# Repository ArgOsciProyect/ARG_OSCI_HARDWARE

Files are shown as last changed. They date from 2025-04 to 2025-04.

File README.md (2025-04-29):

# ARG_OSCI Hardware Implementation Guide



**ARG_OSCI** is an open-source portable oscilloscope platform. This document details the technical implementation of the hardware, focusing on design decisions, construction, and improvement opportunities. It is intended for engineers and advanced users interested in building or modifying the device.

---

## Table of Contents
- [Introduction](#introduction)
- [Design Overview](#design-overview)
- [Implementation Details](#implementation-details)
  - [1. Input Network](#1-input-network)
  - [2. Attenuation Networks](#2-attenuation-networks)
    - [2.1 A/B Attenuation Network](#ab-attenuation-network)
    - [2.2 1/2/3/4 Attenuation Network](#1234-attenuation-network)
    - [2.3 Attenuation Stage Details](#attenuation-stage-details)
  - [3. Amplification Stage](#3-amplification-stage)
  - [4. Signal Filtering](#4-signal-filtering)
  - [5. External ADC Circuit](#5-external-adc-circuit)
  - [6. Transient Comparator Circuit](#6-transient-comparator-circuit)
  - [7. Calibration Square Wave Generator](#7-calibration-square-wave-generator)
  - [8. Connection Status LED Circuit](#8-connection-status-led-circuit)
  - [9. Power Supply](#9-power-supply)
  - [10. ESP32 Connectivity and Decoupling](#10-esp32-connectivity-and-decoupling)
- [Design Files and Resources](#design-files-and-resources)
- [Construction and Improvement Notes](#construction-and-improvement-notes)
  - [1. Assembly and Component Selection](#assembly-and-component-selection)
  - [2. Protection and Safety](#protection-and-safety)
  - [3. Optional Simplifications](#optional-simplifications)
  - [4. Design and Layout](#design-and-layout)
  - [5. PCB Design](#pcb-design)
  - [6. 3D Case Design](#3d-case-design)
- [Pending Tasks and Recommendations](#pending-tasks-and-recommendations)
  - [1. Technical Improvements](#technical-improvements)
  - [2. Documentation and Usability](#documentation-and-usability)
  - [3. Future Development](#future-development)
- [License](#license)
- [Acknowledgements](#acknowledgements)

---

## Introduction

This document describes how to implement the ARG_OSCI hardware, including the rationale behind each design block, construction notes, and suggestions for further development. For usage instructions, refer to the user manual.

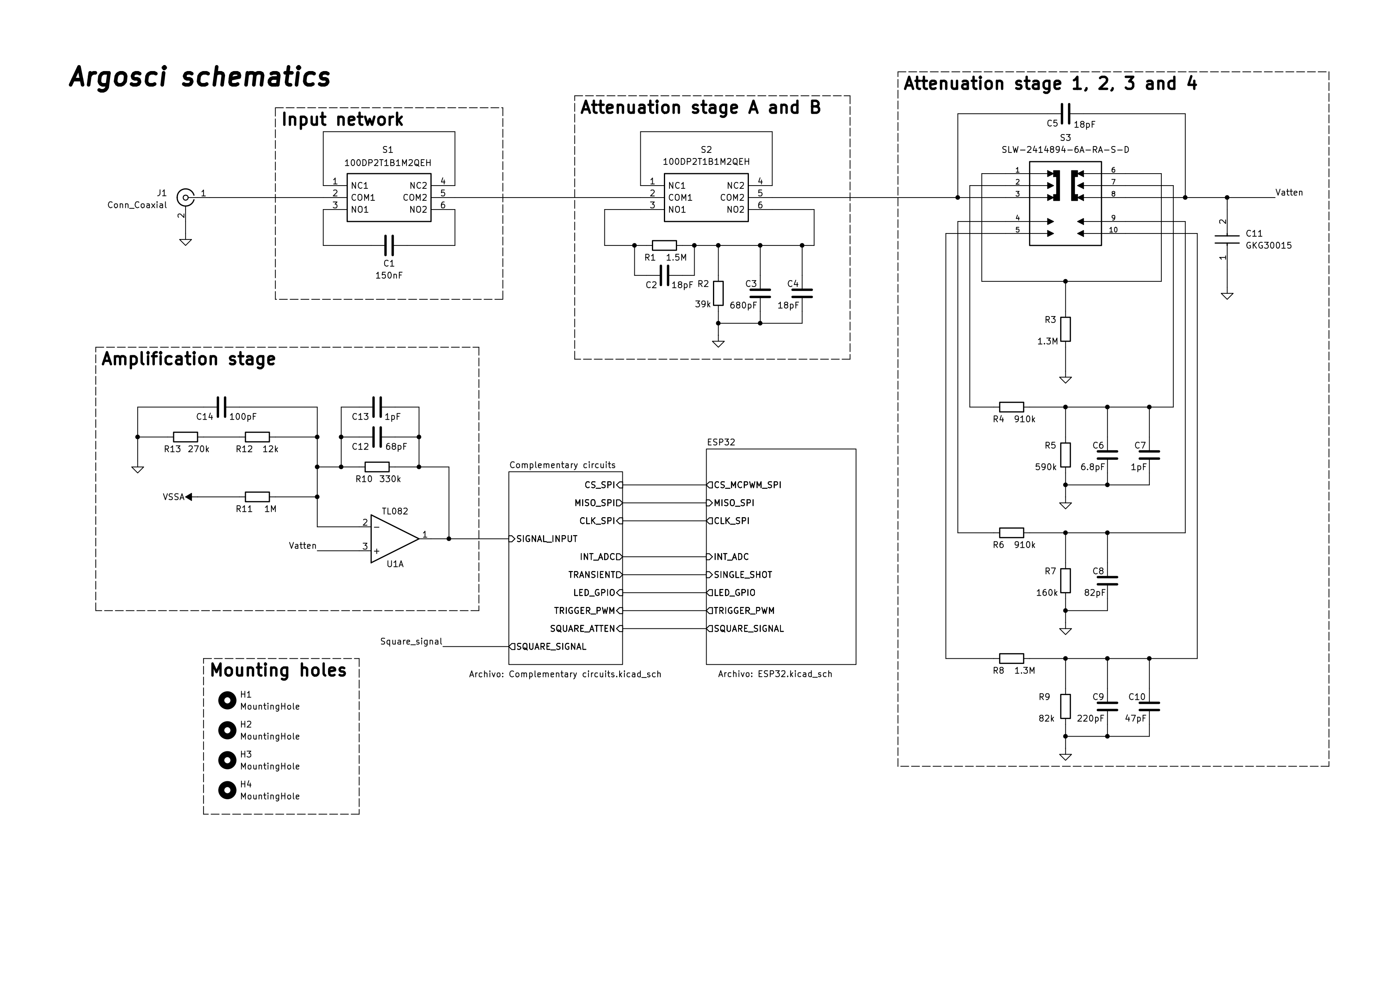
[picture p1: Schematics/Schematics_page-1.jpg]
Argosci Schematics

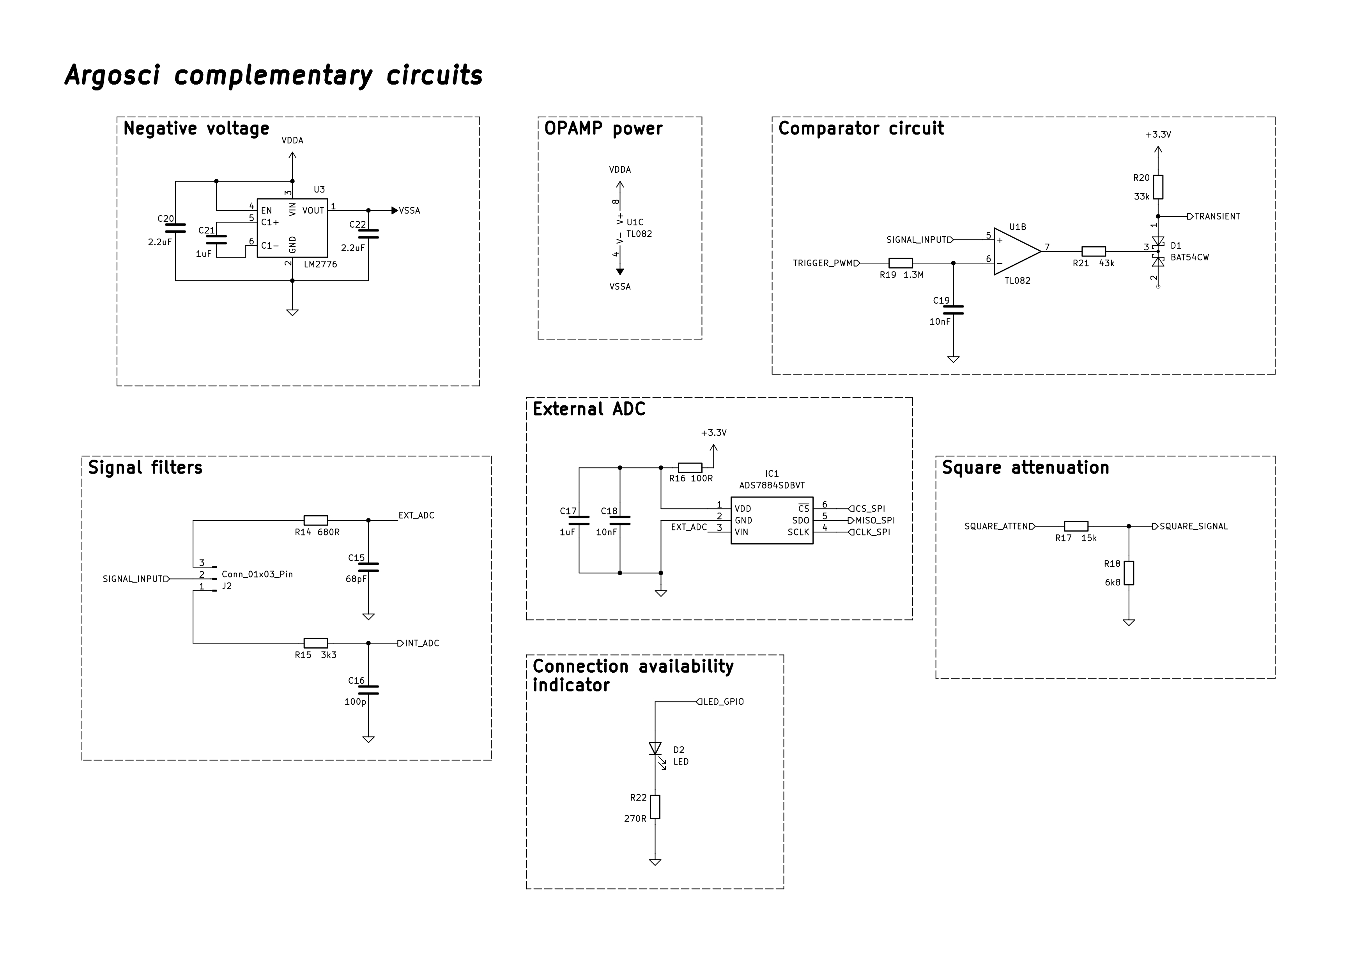
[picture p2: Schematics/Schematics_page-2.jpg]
Argosci complementary circuits

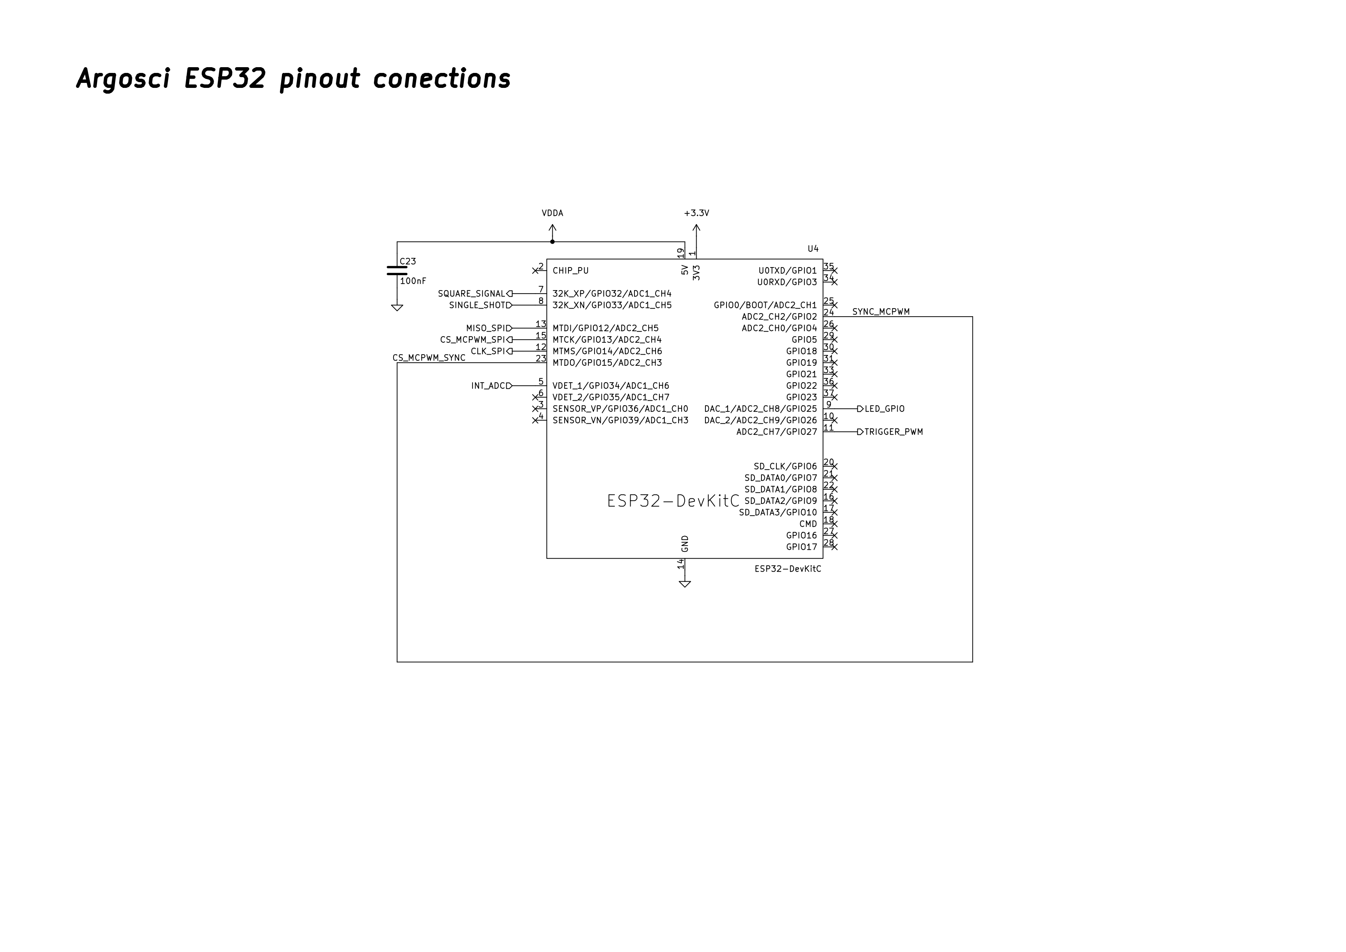
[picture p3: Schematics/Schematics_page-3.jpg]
Argosci ESP32 pinout conections


## Design Overview

The hardware is divided into several functional blocks:

- Input Network
- Attenuation Networks
- Attenuation Stage Details
- Amplification Stage
- Signal Filtering
- External ADC Circuit
- Transient Comparator Circuit
- Calibration Square Wave Generator
- Connection Status LED Circuit
- Power Supply
- ESP32 Connectivity and Decoupling

---

## Implementation Details

### 1. Input Network

The input network provides both AC and DC coupling paths. The AC coupling path includes a series capacitor (150 nF), while the DC path is direct. The 150 nF capacitor must be rated for at least 500V to safely block DC voltages up to the device's maximum scale (±400V). The capacitor value was selected to achieve a cutoff frequency below 1 Hz, considering that the input impedance is always greater than 1MΩ (typically 1070 MΩ to 1500 MΩ, depending on the attenuation setting). This configuration forms a high-pass filter and ensures accurate measurement of AC signals above 1Hz, with a settling time of approximately 1 second after switching to AC coupling.

<!--**Expansion note:** You may add a graph of the high-pass filter response.-->

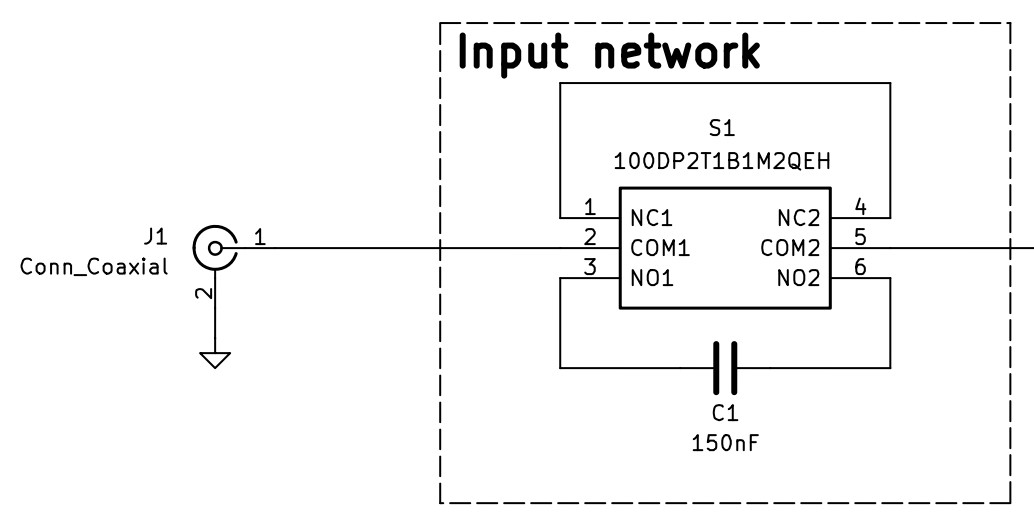
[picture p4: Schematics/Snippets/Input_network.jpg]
Input network


### 2. Attenuation Networks
#### 2.1. A/B Attenuation Network
Provides coarse attenuation (e.g., ×40) using resistor dividers and mechanical switches (2P2T selector switch).

#### 2.2. 1/2/3/4 Attenuation Network
Provides fine attenuation (e.g., ×2.4), yielding eight selectable voltage ranges in combination with the A/B network. This stage also uses mechanical switches (2P4T selector switch) and resistor divider networks for attenuation.

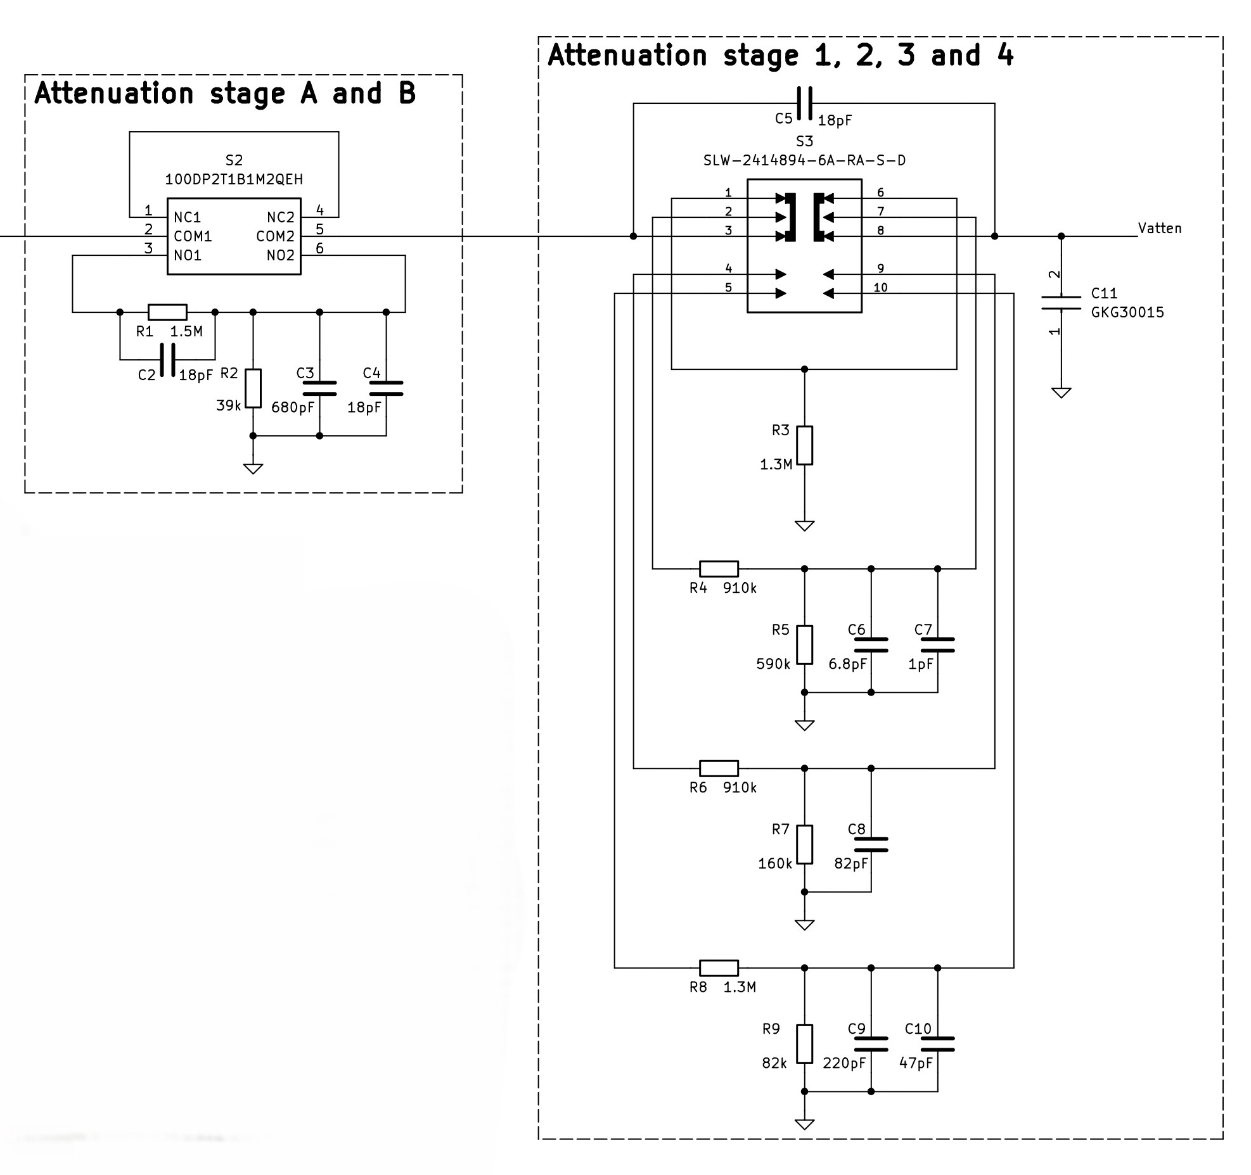
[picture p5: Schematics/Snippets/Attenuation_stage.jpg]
Attenuation stage


#### 2.3. Attenuation Stage Details

The decision to use resistive divider networks in the attenuation stage was made after a thorough analysis of various possible configurations. Different approaches were evaluated based on criteria such as ease of compensation, the number of switches required for implementation, the impedance presented to the amplifier, and other relevant aspects. The chosen solution represents a balance between precision, simplicity, and robustness for the application.

The attenuation stage is designed to maintain an input impedance greater than 1 MΩ. To compensate for the effects of parasitic capacitances —particularly those introduced by the amplifier— capacitors are included in the attenuation network. The total input capacitance of the device is kept below 20pF. Components are selected with 5% tolerance (1% for higher precision if desired), resistors are rated at 1/4 W, and capacitors are rated for at least 25 V, except for the series capacitor in stage B, which must withstand up to 500 V to safely attenuate signals up to 400V when required.

A trimmer capacitor is placed at the amplifier input to allow fine adjustment and compensate for variations in the amplifier’s input capacitance and other component tolerances. The trimmer is adjustable up to 20pF, with a minimum value of approximately 4.2pF, ensuring a flat frequency response across the device’s bandwidth. The most sensitive stage to these variations is A2, as it has the smallest capacitance in parallel with the amplifier, making it more susceptible to frequency response deviations.

### 3. Amplification Stage

The amplification stage uses the TL082 operational amplifier, chosen for its suitable bandwidth, slew rate, operating ranges, low associated errors, low cost, and ease of sourcing. Two feedback configurations are implemented: the inverting configuration is used to set the signal offset (centering it within the ADC input range using the –5V rail), while the non-inverting configuration amplifies the measured signal to maximize the ADCs' dynamic range.

To minimize errors due to input bias currents, high-value resistors are used in the feedback network. This necessitated the inclusion of a capacitive compensation network (without the need for a trimmer in this case).

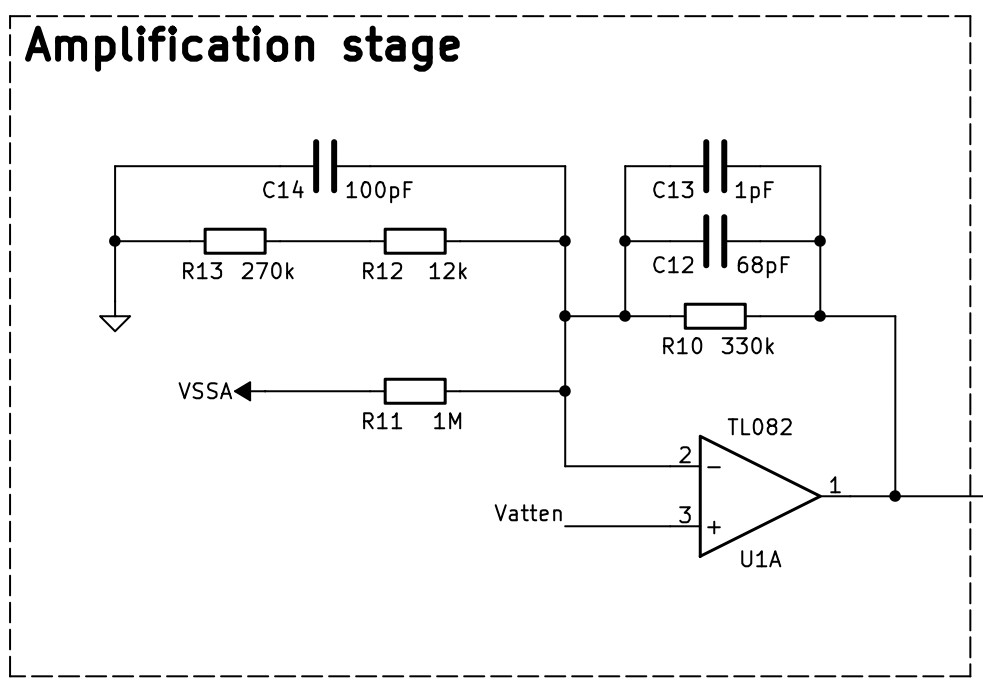
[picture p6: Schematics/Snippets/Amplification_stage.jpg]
Amplification stage

<!--**Expansion note:** Discuss op-amp selection criteria, possible improvements, and test results.-->

#### Design Considerations and Potential Improvements
- **Resistor Value Optimization:** It is being considered to reduce the values of the feedback resistors, as the error from bias currents is relatively low. Lowering these values could allow the removal of the compensation network, though a capacitor should still be retained to filter noise from the –5V supply. This change would increase the device's power consumption and should be evaluated accordingly.
- **Negative Voltage Limiter:** It is recommended to add a negative voltage limiter at the amplifier output. While the amplifier typically saturates at positive voltages (not damaging the ADCs), under certain conditions it may output voltages below 0V, which could potentially harm the ADCs.

### 4. Signal Filtering

A conventional first-order RC low-pass filter is used for signal filtering. The filters are designed based on the input capacitance of the ADCs used in each case. Two separate filter networks are implemented, allowing the user to select which ADC to use. For each network, the cutoff frequency is set to the maximum frequency that the device can accurately measure with the selected ADC.

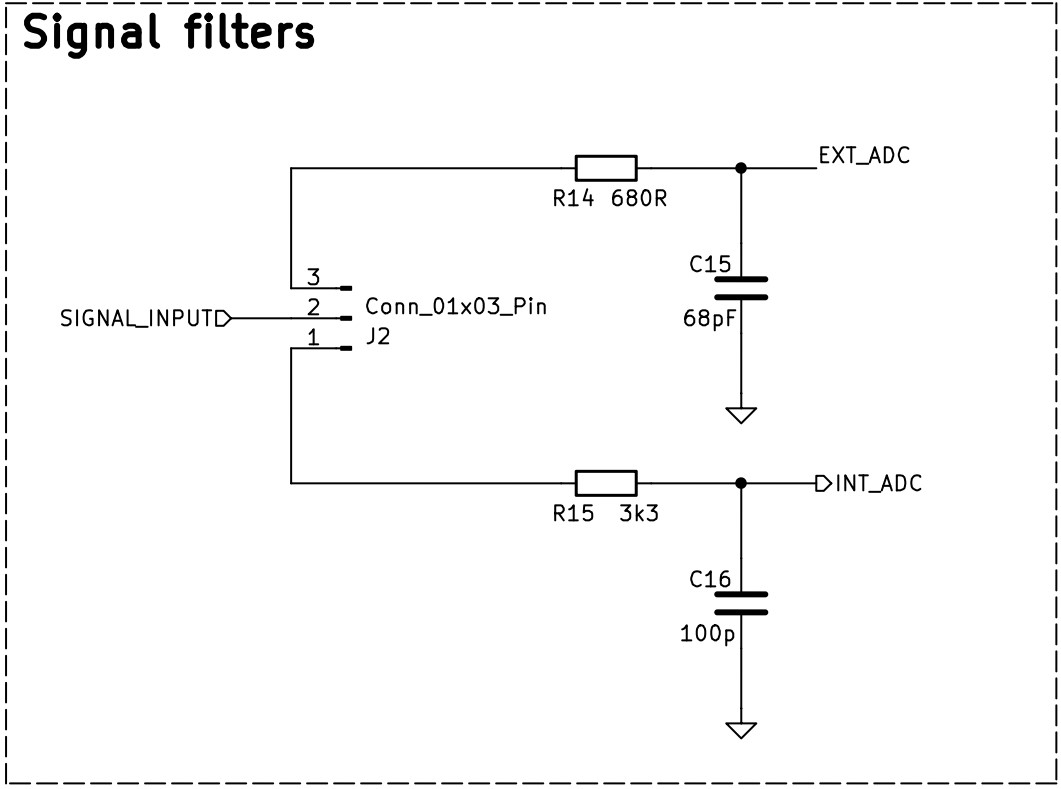
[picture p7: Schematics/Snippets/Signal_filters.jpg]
Signal filters


#### Design Considerations and Potential Improvements
- **Filter Effectiveness Review:** It has been observed that at higher frequencies, aliasing phenomena may occur, distorting the measured signal and its frequency spectrum. A review of the filter effectiveness is recommended, and higher-order filters may be considered to improve performance and reduce aliasing effects.

### 5. External ADC Circuit

The external ADC (ADS7884) circuit is designed following the manufacturer's recommendations. For SPI communication with the ESP32, the layout ensures physical proximity between the ADS7884 and the relevant ESP32 pins, with all SPI traces kept as short and equal in length as possible. These measures are critical to maintain signal integrity at the 40 MHz communication frequency.

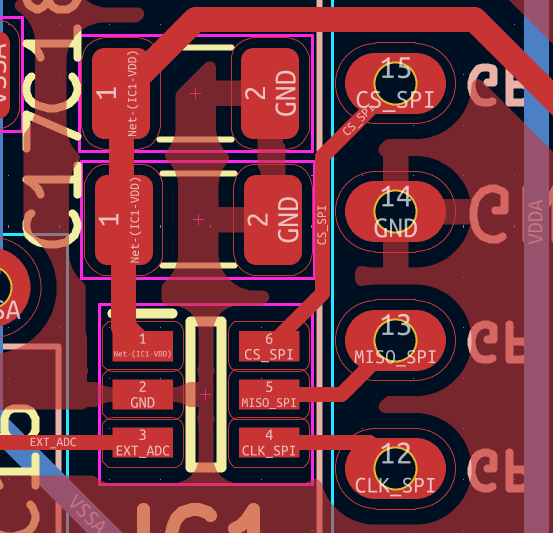
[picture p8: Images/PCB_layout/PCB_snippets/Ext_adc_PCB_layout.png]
External ADC - PCB layout


The ADS7884 is powered by the 3.3 V supply provided by the ESP32's onboard regulator, which also serves as the ADC's voltage reference. The stability of this voltage is crucial for measurement accuracy. To stabilize the supply, an RC network is implemented, consisting of the manufacturer-recommended capacitors and a 100 Ω resistor (subject to further review), in line with the recommended power supply impedance.

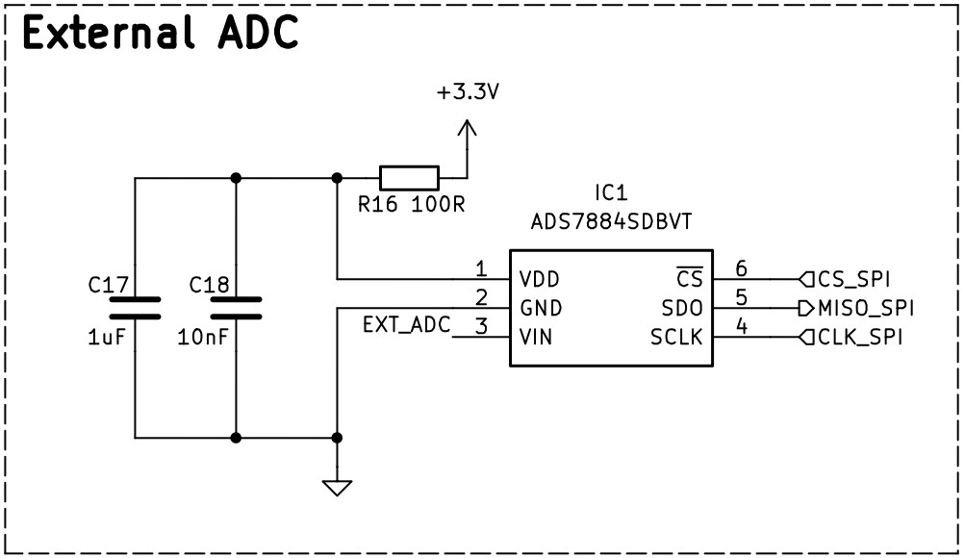
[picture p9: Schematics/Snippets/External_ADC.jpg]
External ADC


#### Design Considerations and Potential Improvements
- **Dedicated Voltage Regulator:** It is recommended to consider adding a dedicated voltage regulator for the ADC to ensure a stable reference voltage, independent of noise from the ESP32 supply.
- **Power Supply Filtering Review:** The value of the series resistor and the overall RC network should be reviewed and optimized to further improve voltage stability and measurement quality.
- **EMI/Environmental Noise Shielding:** The ADC has shown sensitivity to environmental interference and noise. It is recommended to implement shielding methods on the PCB or enclosure to reduce these effects and improve measurement reliability.

### 6. Transient Comparator Circuit

The transient comparator circuit enables the detection and reading of aperiodic (transient) signals. It consists of three main parts, each with a specific function:

#### RC Filter
The RC filter stabilizes a PWM signal generated by the ESP32. This PWM signal is set to have an average voltage equal to the trigger level selected in the application for signal visualization. The resulting DC voltage serves as the reference level for the comparator.

#### Comparator (TL082)
The remaining amplifier in the TL082 IC is configured as a comparator. It compares the measured signal to the reference voltage from the RC filter. When the input signal exceeds the trigger threshold, the comparator switches its output state. This transition is recognized as a transient event, which is then communicated to the application for display.

#### Digital Signal Adapter
The digital adapter converts the output of the comparator to voltage levels that are safe and readable by the ESP32: 3.3 V (minimum 2.475 V) for logic high and 0 V (maximum 0.825 V) for logic low. This is achieved using a BAT54 (or BAT85) diode in combination with a resistive divider, which limits current and ensures the output is pulled close to 0 V when the comparator switches to its negative output.

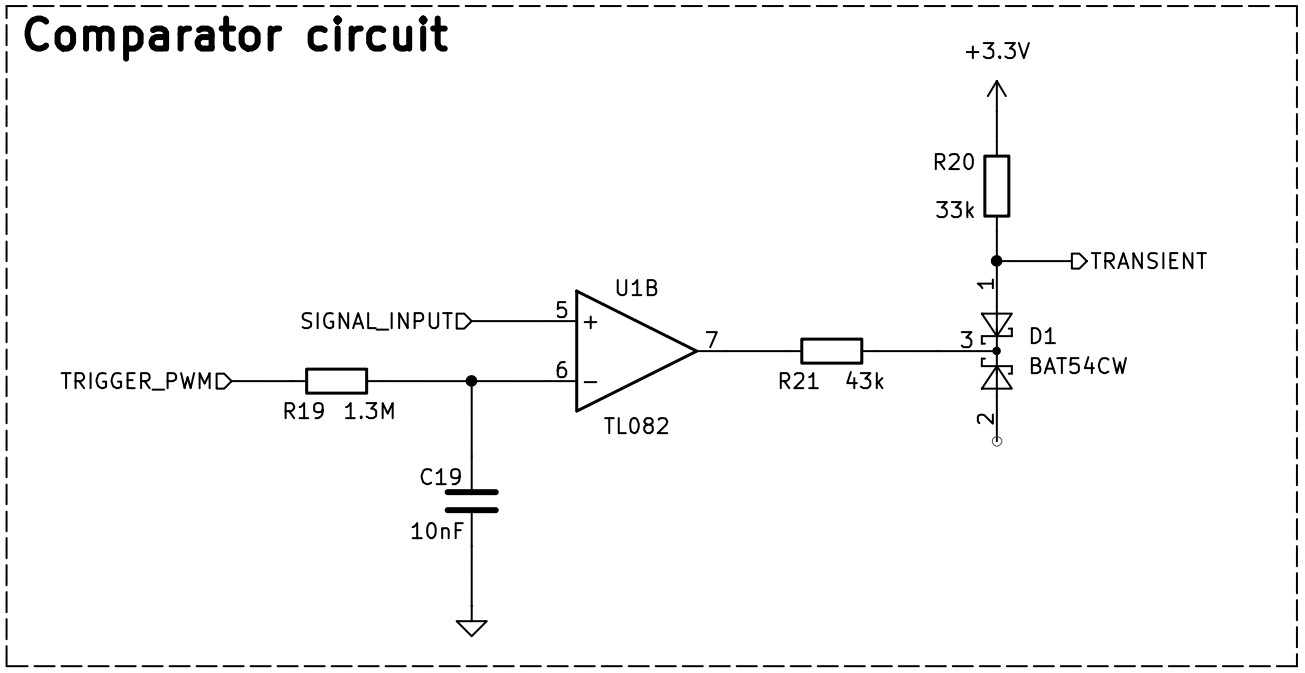
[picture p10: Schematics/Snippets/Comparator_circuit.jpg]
Comparator circuit


<!--**Expansion note:** Add timing diagrams or oscilloscope captures of transient detection events.-->

### 7. Calibration Square Wave Generator

The calibration circuit operates using a 1 kHz square wave signal provided by the ESP32, with levels ranging from 0 V to 3.3 V. This signal is attenuated to approximately 30% of its original amplitude using a resistive divider (15 kΩ and 6.8 kΩ), resulting in a safe level for the A2 stage, which is particularly sensitive to parasitic capacitance. The attenuated signal is used specifically to fine-tune the trimmer capacitor in the A2 stage. The resistor values are selected to minimize current draw and reduce loading on the ESP32 output.

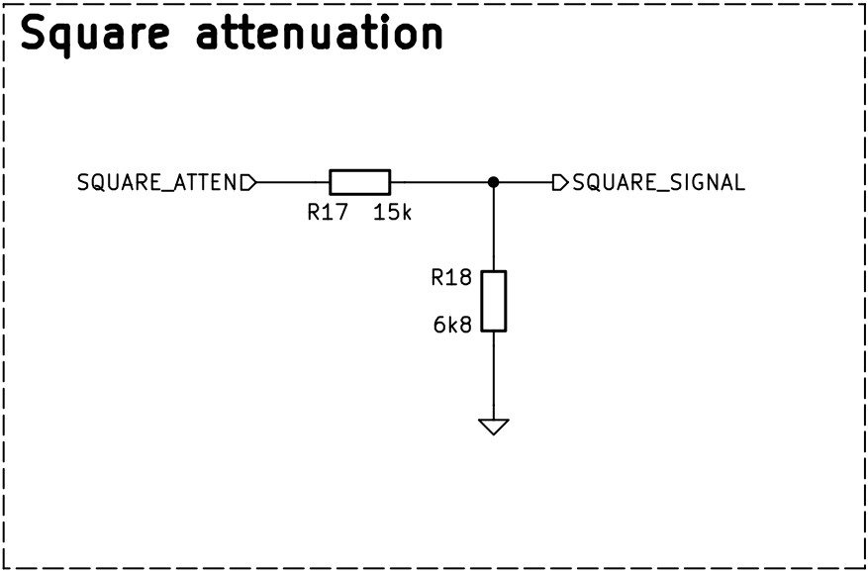
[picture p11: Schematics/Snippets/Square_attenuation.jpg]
Square attenuation


### 8. Connection Status LED Circuit

The purpose of this LED is to indicate when the ESP32 board is ready to accept WiFi connections and begin operation. While the LED is off, the device is generating the access point. When the LED turns on, it signals that the user can connect to the device.

A 5 mm LED is used to increase visibility. A 270 Ω resistor is placed in series, but this value can be adjusted if needed—for example, using a lower resistance to increase brightness. The LED size and resistor value can be modified according to specific design preferences.

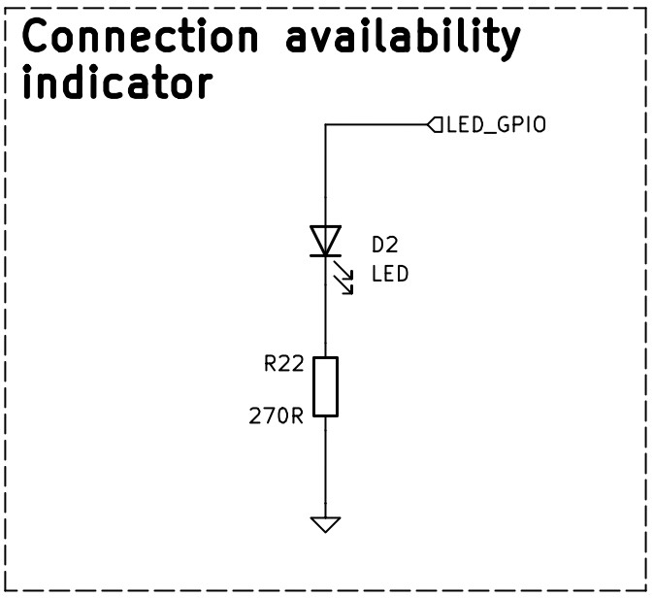
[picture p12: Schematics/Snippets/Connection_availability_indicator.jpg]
Connection availability indicator


### 9. Power Supply
#### 9.1. +5V Supply
- The +5V supply is sourced from the ESP32's 5V pin, which itself is powered via the USB port.
- A diode-capacitor circuit is used between the USB input and the 5V rail. The presence of the diode causes a slight voltage drop below 5V. While this does not affect the operation of the operational amplifiers, it does slightly shift the voltage levels in the comparator circuit and significantly impacts the generation of the –5V rail via the LM2776.

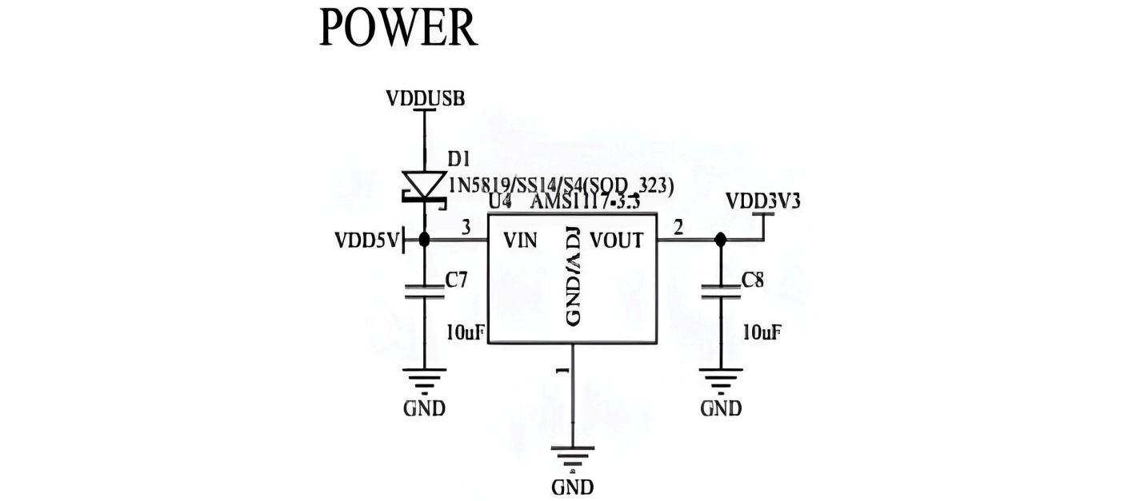
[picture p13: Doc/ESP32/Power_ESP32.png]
Power ESP32

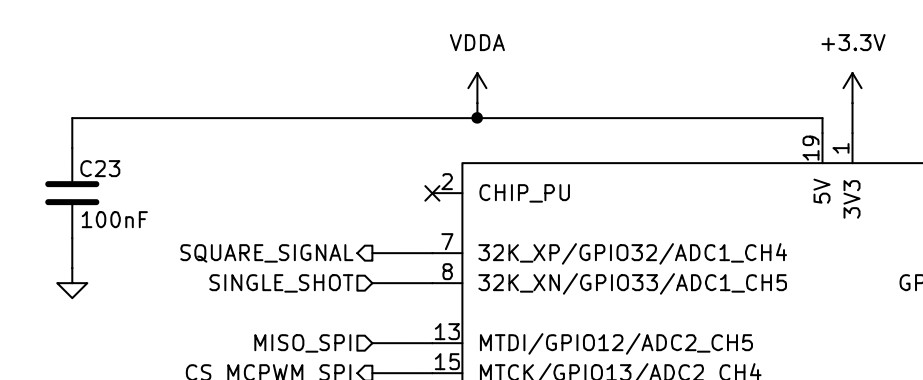
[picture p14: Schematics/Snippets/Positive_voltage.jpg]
Positive voltage


#### 9.2. –5V Supply
- The –5V rail is generated using the LM2776 charge pump IC, implemented according to the manufacturer's recommendations.
- Stabilization and voltage generation capacitors are placed as close as possible to the LM2776 to ensure proper operation and minimize noise.
- Since the LM2776 inverts and slightly alters the positive supply voltage, software and firmware corrections are applied to compensate for any offset shifts that could affect ADC readings.
- There is a known issue with the LM2776 operation that requires further review to ensure reliable negative voltage generation.

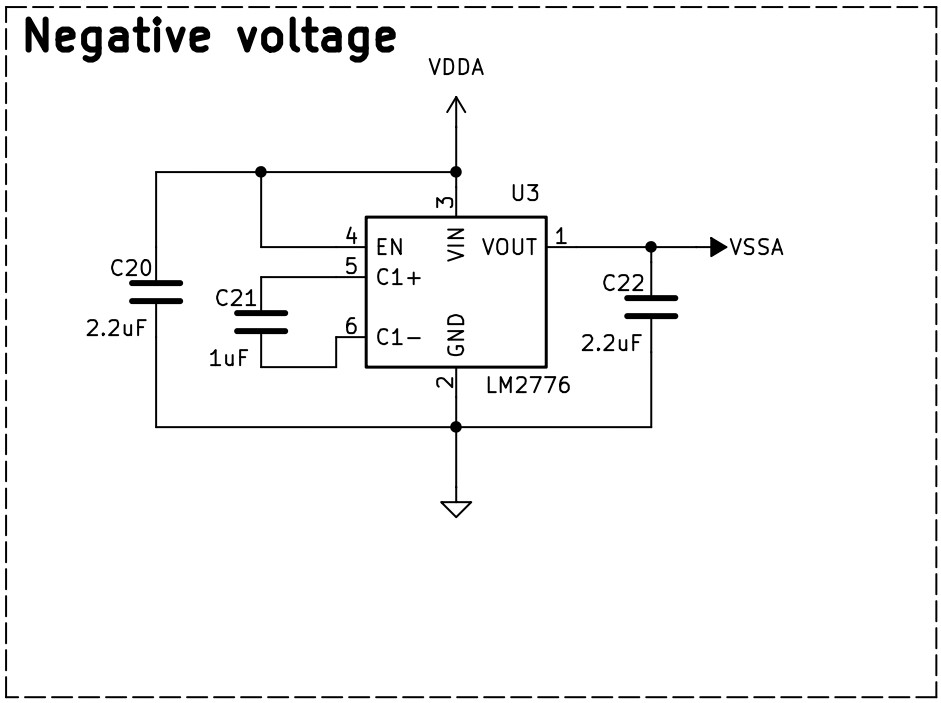
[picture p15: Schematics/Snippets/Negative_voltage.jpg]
Negative voltage


#### 9.3. External Power Option
- The PCB provides access to power supply pins, allowing the circuit to be powered externally. This enables bypassing the micro USB and ESP32 for power delivery, and allows for a higher-quality negative voltage supply if needed.

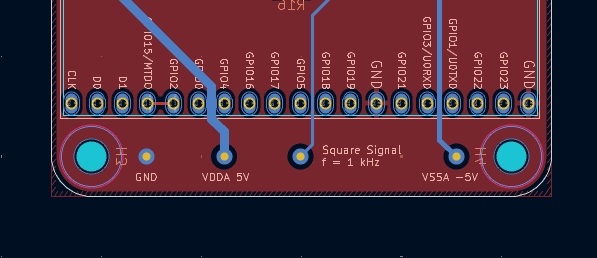
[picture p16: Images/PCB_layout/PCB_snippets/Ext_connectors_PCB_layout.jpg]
External connectors - PCB layout


### 10. ESP32 Connectivity and Decoupling
#### 10.1. Future Improvements
- **Direct Microcontroller Integration:** There are plans to redesign the hardware to use only the ESP32 microcontroller chip, eliminating the full devkit. This would:
  - Reduce the overall PCB size
  - Simplify flashing and programming
  - Improve signal routing and reduce parasitic effects
  - Allow for more flexible and compact enclosure designs
  - Potentially reduce cost and improve reliability

---

## Design Files and Resources
- **Schematics**: Complete circuit diagrams for all hardware blocks. Located in the ['Schematics'](Schematics/) folder.
- **PCB Layout**: Proposed PCB design with Gerber files for manufacturing. Located in the ['PCB'](PCB/) folder.
- **BOM**: Bill of Materials with recommended part numbers and tolerances. Available in the ['BOM'](BOM/) folder.
- **3D Enclosure**: Printable STL files for the device enclosure. Available in the ['Case3D'](Case3D/) folder.
- **LTspice Simulations**: Circuit simulation files for analysis and design validation. Recommended folder name: ['LTspice_Simulations'](LTspice_Simulations/).

> **Additional files:**
- Technical documentation and manuals in the ['Doc'](Doc/) folder.
- Images and diagrams in the ['Images'](Images/) folder.

---

## Construction and Improvement Notes

### 1. Assembly and Component Selection
- For best measurement accuracy, use 1% tolerance components in the following order of priority:
  1. Amplification circuit (affects all scales and frequencies)
  2. A/B attenuation circuit (affects upper half of scales, 40x attenuation)
  3. Series capacitor in the 1/2/3/4 attenuation circuit (affects all scales at high frequency)
  4. 1/2/3/4 attenuation circuit (affects all scales)
  5. Input filters to the ADCs
  6. Remaining components
- Both the internal ESP32 ADC and the external ADC present nonlinearities, though the external ADC is more accurate.
- Pay special attention to the correct wiring of the attenuation scales and selector logic during assembly. Errors here can damage multiple components.

### 2. Protection and Safety
- It is strongly recommended to add fuse-varistor protection circuits to safeguard the integrity of the attenuation stages:
  - 12.5 V varistor in stage A
  - 500 V varistor in stage B
  - 5 V varistor in stage 1 (direct path to the op-amp)

Note: The current PCB does not include footprints for these components.

### 3. Optional Simplifications
- The following stages can be omitted to reduce PCB size, simplify construction, or save on materials:
  - B attenuation stage (if high-voltage operation is not required)
  - AC/DC selection stage
  - Single-shot mode stage
  - ADC input filter for any unused ADC
- If the LM2776 IC is unavailable, substitute with a similar IC (ensure correct pinout) or provide a negative voltage rail externally.

### 4. Design and Layout
- PCB layout can be further optimized for EMC and signal integrity.
- The enclosure design may be adapted or improved for robustness.
- More compact PCB designs are planned, including protection features and direct microcontroller integration (without the devkit).

### 5. PCB Design
The PCB was designed following standard practices, prioritizing functional block separation and signal integrity as described in previous sections. No special layout considerations beyond those already mentioned were required.

### 6. 3D Case Design
The 3D case was designed to fit the PCB and provide basic protection. No special design constraints or requirements were considered beyond ensuring proper fit.

> **Note:** If electromagnetic shielding is desired to reduce interference, keep in mind that the device connects via WiFi. Any shielding solution should be implemented with care to avoid degrading wireless communication performance.

---

## Pending Tasks and Recommendations

### 1. Technical Improvements
- Complete a detailed error analysis and document the results for all acquisition paths.
- Review and improve the negative power supply design, including alternatives to the LM2776.
- Consider implementing higher-order input filters to improve signal fidelity and reduce aliasing.
- Evaluate and document the effectiveness of protection circuits and their impact on measurement reliability.

### 2. Documentation and Usability
- Provide step-by-step assembly instructions and detailed test procedures.
- Add troubleshooting and known issues sections to assist users during assembly and operation.

### 3. Future Development
- Develop and release more compact PCB designs with integrated protections and without the devkit.
- Explore the possibility of omitting or modularizing optional stages for different use cases.

---

## License

This hardware project is licensed under the [CERN-OHL-W v2](https://gitlab.com/ohwr/project/cernohl/-/wikis/home).

---

## Acknowledgements

This project is part of the **ARG_OSCI** oscilloscope visualization tool suite. For firmware and software, visit the [ARG_OSCI_FIRMWARE](https://github.com/ArgOsciProyect/ARG_OSCI_FIRMWARE) and [ARG_OSCI_APP](https://github.com/ArgOsciProyect/ARG_OSCI_APP) repositories.

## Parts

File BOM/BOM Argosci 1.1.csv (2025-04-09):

Section | Component | Value | Observations | Notes | Quantity | Precio unitario USD | Total | Se agrega el led de indicación y se incorpora la resistencia de filtro del ADC
Microcontroller | ESP32 | - | - | NODEMCU-32S | 1 | 5 | 5
Input Network | Capacitors | 150 nF | 5% - 500 V | Ceramic or multilayer - 1206 | 1 | 0,6 | 0,6
 | Selectors | 2P2T | 500 V | 100DP2T1B1M2QEH (or similar) | 1 | 0,79 | 0,79
 | BNC Input | BNC Hembra | - | BNC-6252H7 (or compatible BNC Female Right Angle PCB Connector) | 1 | 1,61 | 1,61
Attenuation Network | Resistors | 1,5 MΩ | 5% - 1/4 W | 1206 | 1 | 0,1 | 0,1
 |  | 39 kΩ | 5% - 1/4 W |  | 1 | 0,1 | 0,1
 |  | 1,3 MΩ | 5% - 1/4 W |  | 2 | 0,1 | 0,2
 |  | 910 kΩ | 5% - 1/4 W |  | 2 | 0,1 | 0,2
 |  | 590 kΩ | 5% - 1/4 W |  | 1 | 0,1 | 0,1
 |  | 160 kΩ | 5% - 1/4 W |  | 1 | 0,1 | 0,1
 |  | 82 kΩ | 5% - 1/4 W |  | 1 | 0,1 | 0,1
 | Capacitors | 18 pF | 5% - 25 V | Ceramic or multilayer - 1206 | 2 | 0,2 | 0,4
 |  | 18 pF | 5% - 500 V |  | 1 | 0,27 | 0,27
 |  | 680 pF | 5% - 25 V |  | 1 | 0,2 | 0,2
 |  | 6,8 pF | 5% - 25 V |  | 1 | 0,2 | 0,2
 |  | 1 pF | 5% - 25 V |  | 1 | 0,2 | 0,2
 |  | 82 pF | 5% - 25 V |  | 1 | 0,2 | 0,2
 |  | 220 pF | 5% - 25 V |  | 1 | 0,2 | 0,2
 |  | 47 pF | 5% - 25 V |  | 1 | 0,2 | 0,2
 |  | Trimmer 30 pF | 25 V | TSCS06-200 // GKG20015 | 1 | 1 | 1
 | Selectors | 2P4T | 25 V | SLW-2414894-6A-RA-S-D | 1 | 0,68 | 0,68
 |  | 2P2T | 500 V | 100DP2T1B1M2QEH (or similar) | 1 | 0,79 | 0,79
Amplification Network | Resistors | 1 MΩ | 5% - 1/4 W | 1206 | 1 | 0,1 | 0,1
 |  | 330 kΩ | 5% - 1/4 W |  | 1 | 0,1 | 0,1
 |  | 270 kΩ | 5% - 1/4 W |  | 1 | 0,1 | 0,1
 |  | 12 kΩ | 5% - 1/4 W |  | 1 | 0,1 | 0,1
 | Capacitors | 68 pF | 5% - 25 V | Ceramic or multilayer - 1206 | 1 | 0,2 | 0,2
 |  | 1 pF | 5% - 25 V |  | 1 | 0,2 | 0,2
 |  | 100 pF | 5% - 25 V |  | 1 | 0,2 | 0,2
 | Operational Amplifier | TL082CP | - | DIP-8 | 1 | 0,85 | 0,85
Filter | Resistors | 680 Ω | 5% - 1/4 W | 1206 | 1 | 0,1 | 0,1
 | Capacitors | 68 pF | 5% - 25 V | Ceramic or multilayer - 1206 | 1 | 0,2 | 0,2
Converter | ADC | ADS7884 | - | SOT-23 | 1 | 4,85 | 4,85
 | Resistors | 100 Ω | 5% - 1/4 W | 1206 | 1 | 0,1 | 0,1
 | Capacitors | 10 nF | 5% - 25 V | Ceramic or multilayer - 1206 | 1 | 0,2 | 0,2
 |  | 1 µF | 5% - 25 V |  | 1 | 0,2 | 0,2
Comparator | Resistors | 33 kΩ | 5% - 1/4 W | 1206 | 1 | 0,1 | 0,1
 |  | 43 kΩ | 5% - 1/4 W |  | 1 | 0,1 | 0,1
 |  | 1,3 MΩ | 5% - 1/4 W |  | 1 | 0,1 | 0,1
 | Capacitors | 10 nF | 5% - 25 V | Ceramic or multilayer - 1206 | 1 | 0,2 | 0,2
 | Operational Amplifier | TL082CP(*) | - | DIP-8 | 0 | 0,85 | 0
 | Diodo | BAT54 (or BAT85) | - | SOT-23-3 | 1 | 0,14 | 0,14
Calibration Signal | Resistors | 15 kΩ | 5% - 1/4 W | 1206 | 1 | 0,1 | 0,1
 |  | 6,8 kΩ | 5% - 1/4 W |  | 1 | 0,1 | 0,1
Connection Indicator | Resistors | 270 Ω | 5% - 1/4 W |  | 1 | 0,1 | 0,1
 | Diode | LED | 10 mA | 5 mm | 1 | 0,29 | 0,29
PCB | - | - | - | - | 1 | 1 | 1
Power Supply | Inverting Converter | LM2776 | - | SOT-23 | 1 | 0,97 | 0,97
 | Capacitors | 2,2 µF | 5% - 25 V | Ceramic or multilayer - 1206 | 2 | 0,2 | 0,4
 |  | 1 µF | 5% - 25 V |  | 1 | 0,2 | 0,2
TOTAL con alimentación |  |  |  |  |  |  | #REF!
Protecciones | Varistores | - | - | - | 3 | 0,25 | 0,75
 | Fusibles | - | - | - | 3 | 0,68 | 2,04
TOTAL con protecciones |  |  |  |  |  |  | #REF!

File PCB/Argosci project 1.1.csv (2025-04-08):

Reference | Value | Footprint | Datasheet | Qty | DNP | Exclude from BOM | Exclude from Board
C1 | 150nF | Capacitor_SMD:C_1206_3216Metric | ~ | 1
C2,C4,C5 | 18pF | Capacitor_SMD:C_1206_3216Metric | ~ | 3
C3 | 680pF | Capacitor_SMD:C_1206_3216Metric | ~ | 1
C6 | 6.8pF | Capacitor_SMD:C_1206_3216Metric | ~ | 1
C7,C13 | 1pF | Capacitor_SMD:C_1206_3216Metric | ~ | 2
C8 | 82pF | Capacitor_SMD:C_1206_3216Metric | ~ | 1
C9 | 220pF | Capacitor_SMD:C_1206_3216Metric | ~ | 1
C10 | 47pF | Capacitor_SMD:C_1206_3216Metric | ~ | 1
C11 | GKG30015 | footprints:GKG30015 | https://media.digikey.com/pdf/Data%20Sheets/Sprague-Goodman%20PDFs/Ceramic%20Dielectric%20Trimmer%20Caps.pdf | 1
C12,C15 | 68pF | Capacitor_SMD:C_1206_3216Metric | ~ | 2
C14 | 100pF | Capacitor_SMD:C_1206_3216Metric | ~ | 1
C16 | 100p | Capacitor_SMD:C_1206_3216Metric | ~ | 1
C17,C21 | 1uF | Capacitor_SMD:C_1206_3216Metric | ~ | 2
C18,C19 | 10nF | Capacitor_SMD:C_1206_3216Metric | ~ | 2
C20,C22 | 2.2uF | Capacitor_SMD:C_1206_3216Metric | ~ | 2
C23 | 100nF | Capacitor_SMD:C_1206_3216Metric | ~ | 1
D1 | BAT54CW | Package_TO_SOT_SMD:SOT-323_SC-70 | https://assets.nexperia.com/documents/data-sheet/BAT54W_SER.pdf | 1
D2 | LED | LED_THT:LED_D5.0mm | ~ | 1
H1,H2,H3,H4 | MountingHole | MountingHole:MountingHole_3mm | ~ | 4 |  | Excluido del BOM
IC1 | ADS7884SDBVT | footprints:SOT95P280X145-6N | http://www.ti.com/lit/gpn/ads7884 | 1
J1 | Conn_Coaxial | Connector_Coaxial:BNC_Amphenol_B6252HB-NPP3G-50_Horizontal | ~ | 1
J2 | Conn_01x03_Pin | Connector_PinHeader_2.54mm:PinHeader_1x03_P2.54mm_Vertical | ~ | 1
R1 | 1.5M | Resistor_SMD:R_1206_3216Metric | ~ | 1
R2 | 39k | Resistor_SMD:R_1206_3216Metric | ~ | 1
R3,R8,R19 | 1.3M | Resistor_SMD:R_1206_3216Metric | ~ | 3
R4,R6 | 910k | Resistor_SMD:R_1206_3216Metric | ~ | 2
R5 | 590k | Resistor_SMD:R_1206_3216Metric | ~ | 1
R7 | 160k | Resistor_SMD:R_1206_3216Metric | ~ | 1
R9 | 82k | Resistor_SMD:R_1206_3216Metric | ~ | 1
R10 | 330k | Resistor_SMD:R_1206_3216Metric | ~ | 1
R11 | 1M | Resistor_SMD:R_1206_3216Metric | ~ | 1
R12 | 12k | Resistor_SMD:R_1206_3216Metric | ~ | 1
R13 | 270k | Resistor_SMD:R_1206_3216Metric | ~ | 1
R14 | 680R | Resistor_SMD:R_1206_3216Metric | ~ | 1
R15 | 3k3 | Resistor_SMD:R_1206_3216Metric | ~ | 1
R16 | 0R | Resistor_SMD:R_1206_3216Metric | ~ | 1
R17 | 15k | Resistor_SMD:R_1206_3216Metric | ~ | 1
R18 | 6k8 | Resistor_SMD:R_1206_3216Metric | ~ | 1
R20 | 33k | Resistor_SMD:R_1206_3216Metric | ~ | 1
R21 | 43k | Resistor_SMD:R_1206_3216Metric | ~ | 1
R22 | 270R | Resistor_SMD:R_1206_3216Metric | ~ | 1
S1,S2 | 100DP2T1B1M2QEH | footprints:100DP2T1B1M2QEH | https://configured-product-images.s3.amazonaws.com/2D/specs/100DP2T1B1M2QEH.pdf | 2
S3 | SLW-2414894-6A-RA-S-D | footprints:SW_SLW-2414894-6A-RA-S-D |  | 1
U1 | TL082 | Package_DIP:DIP-8_W7.62mm | http://www.ti.com/lit/ds/symlink/tl081.pdf | 1
U3 | LM2776 | Package_TO_SOT_SMD:SOT-23-6 | http://www.ti.com/lit/ds/symlink/lm2776.pdf | 1
U4 | ESP32-DevKitC | PCM_Espressif:ESP32-DevKitC | https://docs.espressif.com/projects/esp-idf/zh_CN/latest/esp32/hw-reference/esp32/get-started-devkitc.html | 1

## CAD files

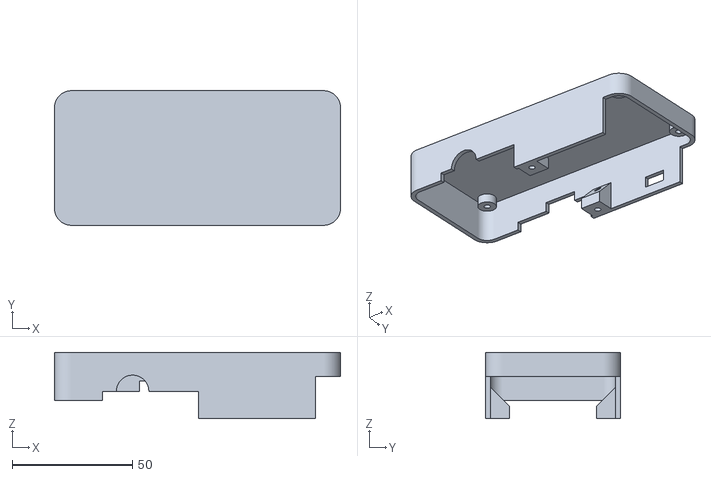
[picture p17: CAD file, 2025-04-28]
Case3D/Argosci 1.1 bot.stl
119.0 x 56.0 x 27.5

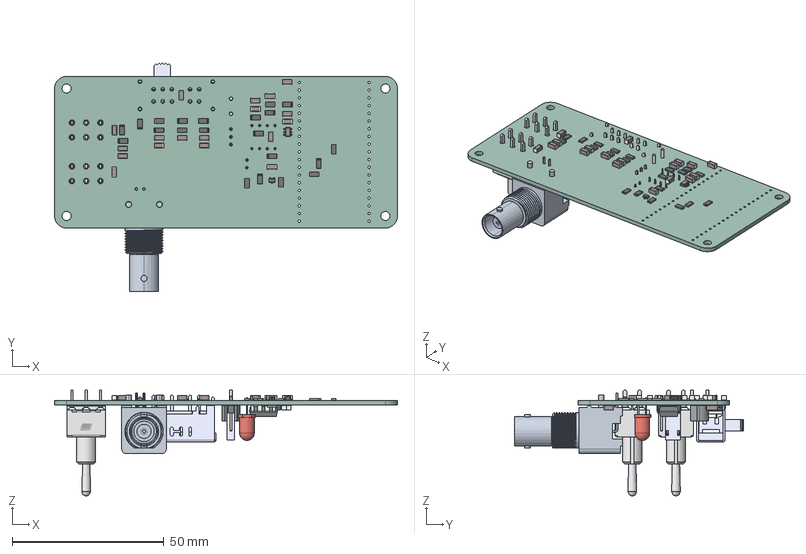
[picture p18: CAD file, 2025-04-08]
Schematics/Argosci project/Argosci project.step
113.0 x 75.3 x 34.9 mm
R_1206_3216Metric x 22
C_1206_3216Metric x 22
SOT-323_SC-70
BODY-SOT
LEAD-SOT x 6
PinHeader_1x03_P2.54mm_Vertical
Leads
Same_Sky_SLW-2414894-6A-RA-S-D
DIP-8_W7.62mm
SOT-23-6
100DP2T1B1M2QEH x 2
LED_D5.0mm
Proyecto integrador 1.1_PCB

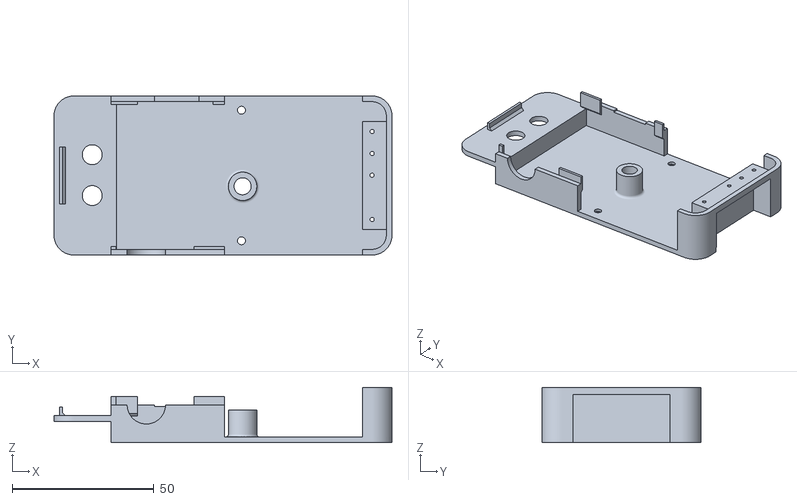
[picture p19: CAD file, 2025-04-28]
Case3D/Argosci 1.1 top.stl
119.0 x 56.0 x 19.5

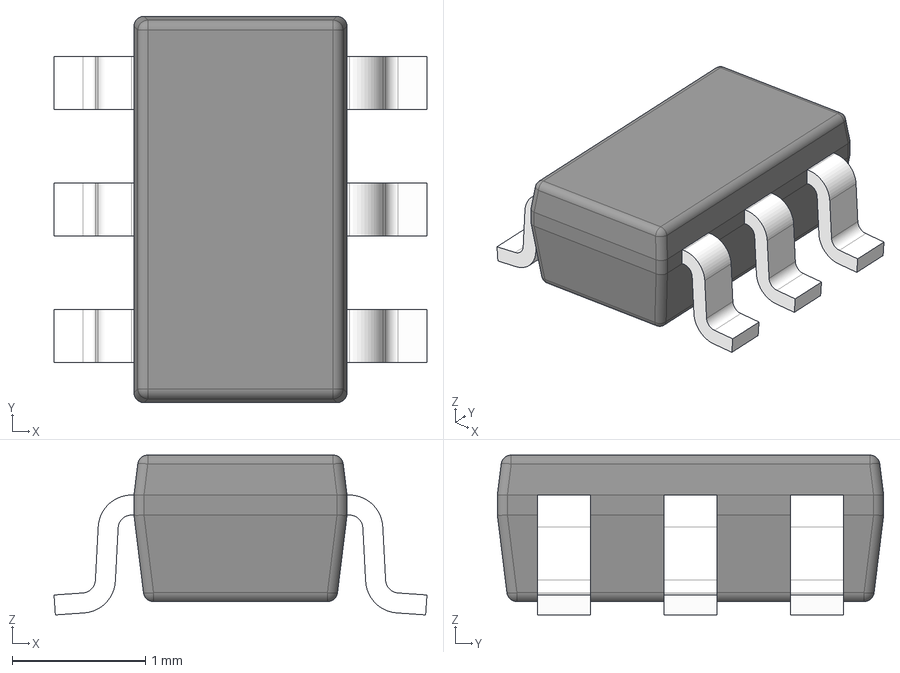
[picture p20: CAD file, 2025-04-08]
Schematics/3dmodels/ADS7884SDBVT.stp
2.80 x 2.90 x 1.20 mm
BODY-SOT
LEAD-SOT x 6

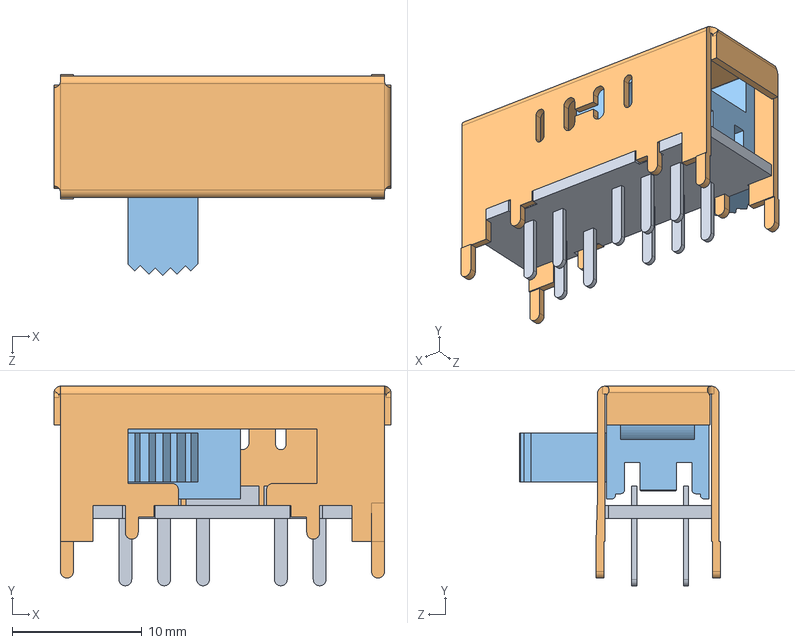
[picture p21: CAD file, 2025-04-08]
Schematics/3dmodels/Same_Sky_SLW-2414894-6A-RA-S-D.step
26.0 x 15.4 x 15.5 mm

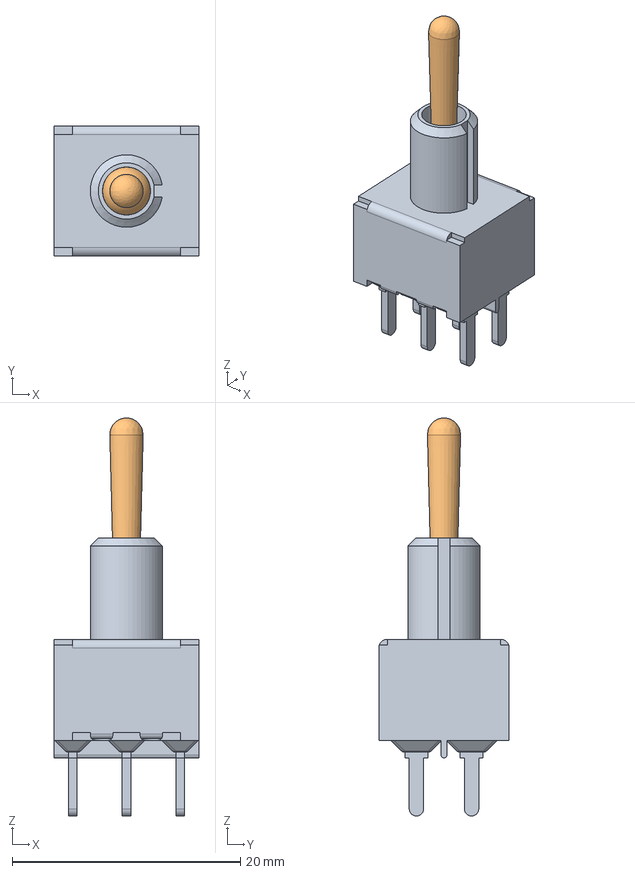
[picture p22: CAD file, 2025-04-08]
Schematics/3dmodels/100DP2T1B1M2QEH.stp
12.7 x 11.4 x 34.9 mm

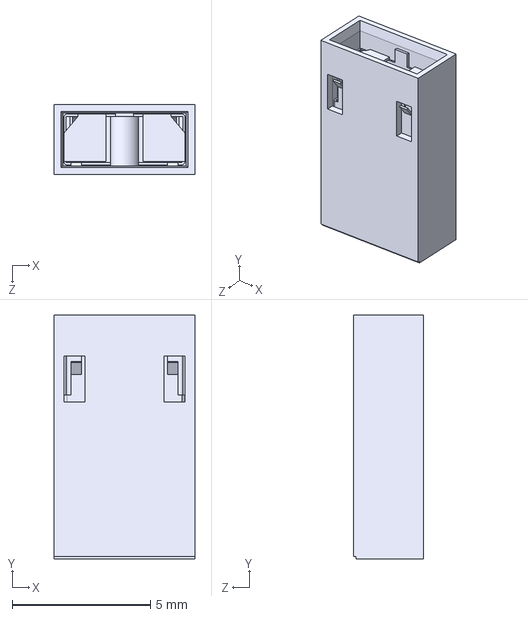
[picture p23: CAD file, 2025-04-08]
Schematics/3dmodels/15-29-1025.stp
5.08 x 8.81 x 2.54 mm

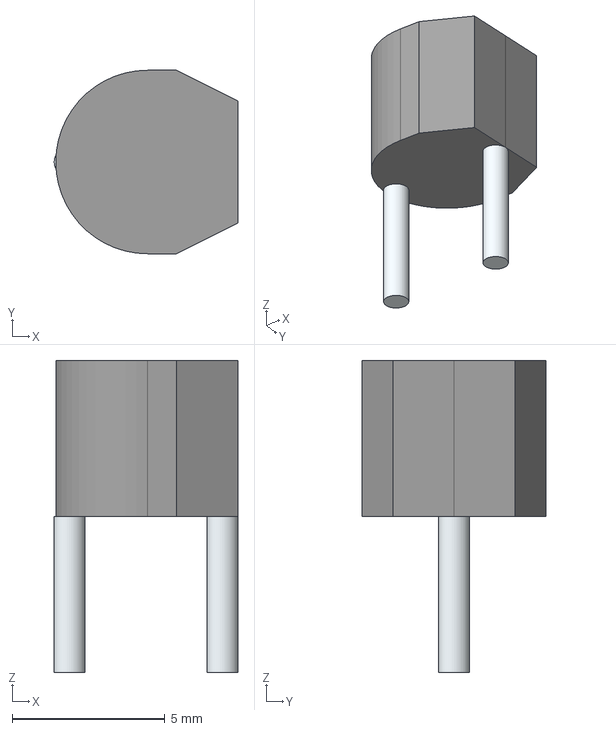
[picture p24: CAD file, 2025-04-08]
Schematics/3dmodels/GKG30015.stp
6.00 x 6.00 x 10.2 mm
Leads

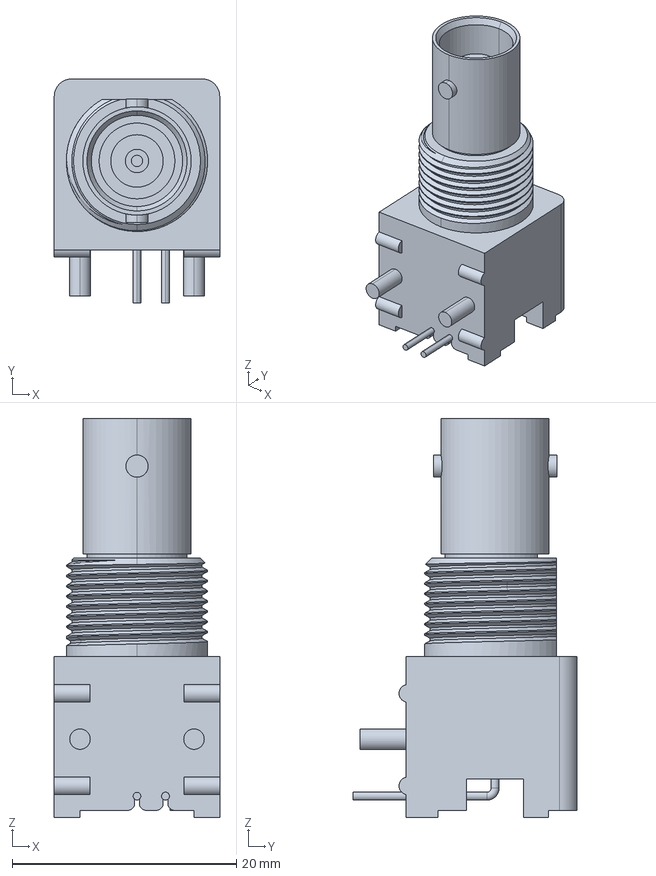
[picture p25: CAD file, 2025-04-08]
Schematics/3dmodels/5227161-1.stp
14.8 x 20.0 x 35.6 mm

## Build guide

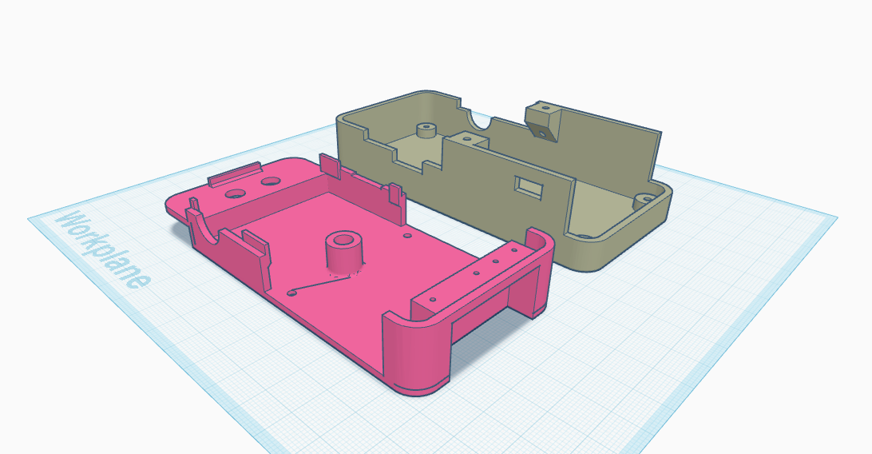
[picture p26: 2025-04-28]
Images/3D-printed_case/Front-Right_Isometric-Argosci_divided_case.png

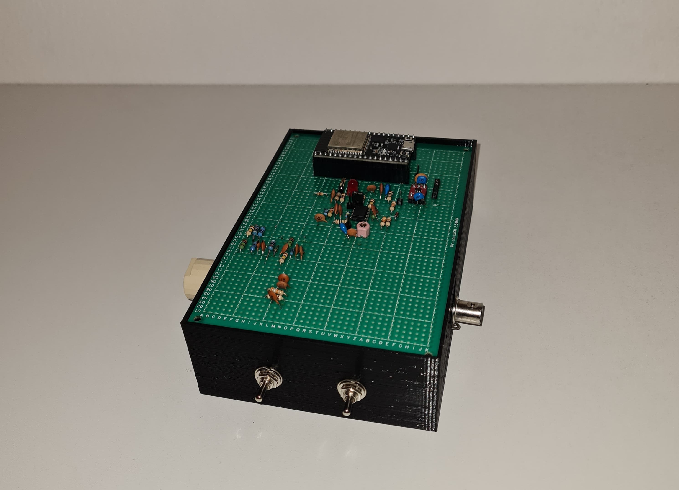
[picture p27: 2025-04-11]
Images/Real_device_assembled/Argosci_Through-hole_prototype.jpg

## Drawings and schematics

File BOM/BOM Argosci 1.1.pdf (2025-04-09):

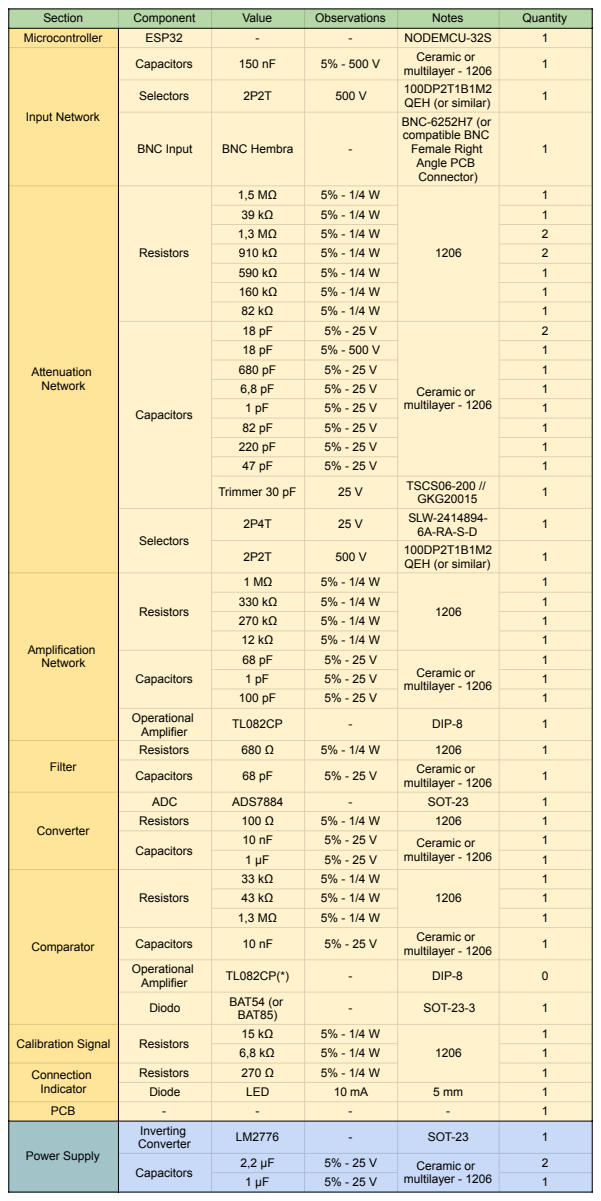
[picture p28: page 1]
Section; Component; Value; Observations; Notes; Quantity; Microcontroller; ESP32; NODEMCU-32S; Input Network; Capacitors; Ceramic or; multilayer - 1206; Selectors; QEH (or similar); BNC Input; BNC Hembra; BNC-6252H7 (or compatible BNC Female Right Angle PCB Connector); Attenuation Network; Resistors; Ceramic or multilayer - 1206; Trimmer 30 pF; TSCS06-200 //; GKG20015; SLW-2414894-; Amplification Network; Operational; Amplifier; DIP-8; Filter; Converter; ADC; ADS7884; SOT-23; Comparator; Diodo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

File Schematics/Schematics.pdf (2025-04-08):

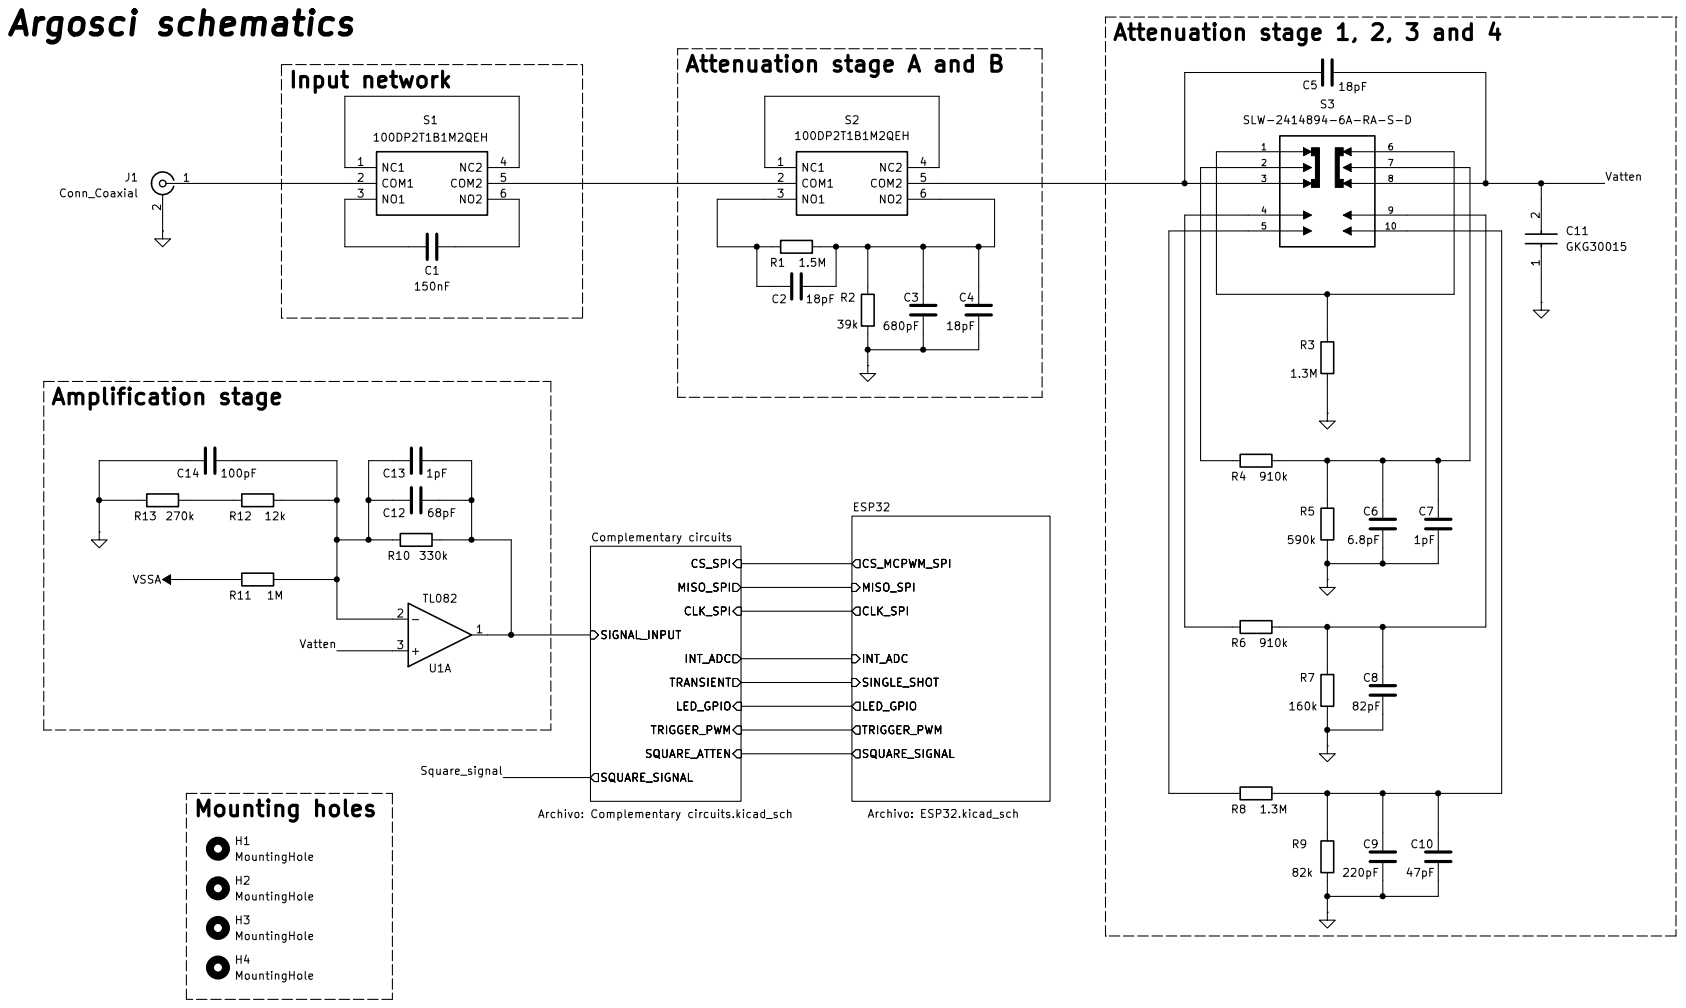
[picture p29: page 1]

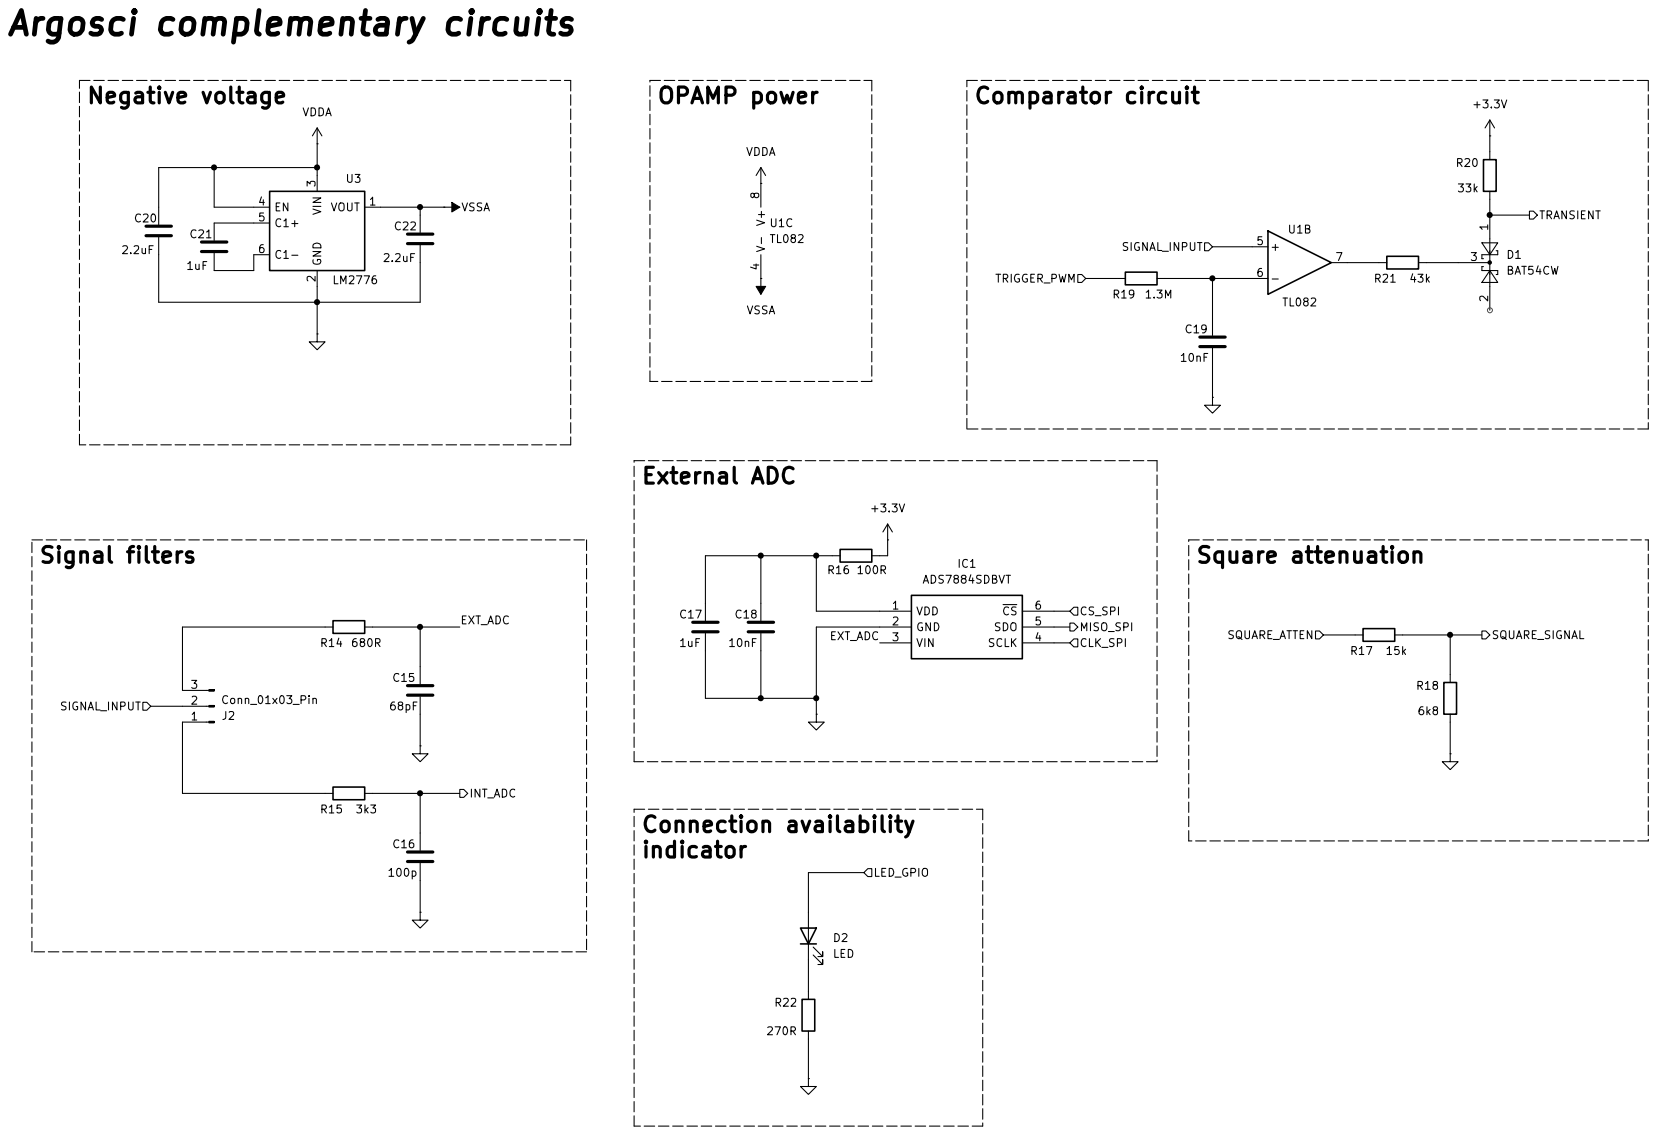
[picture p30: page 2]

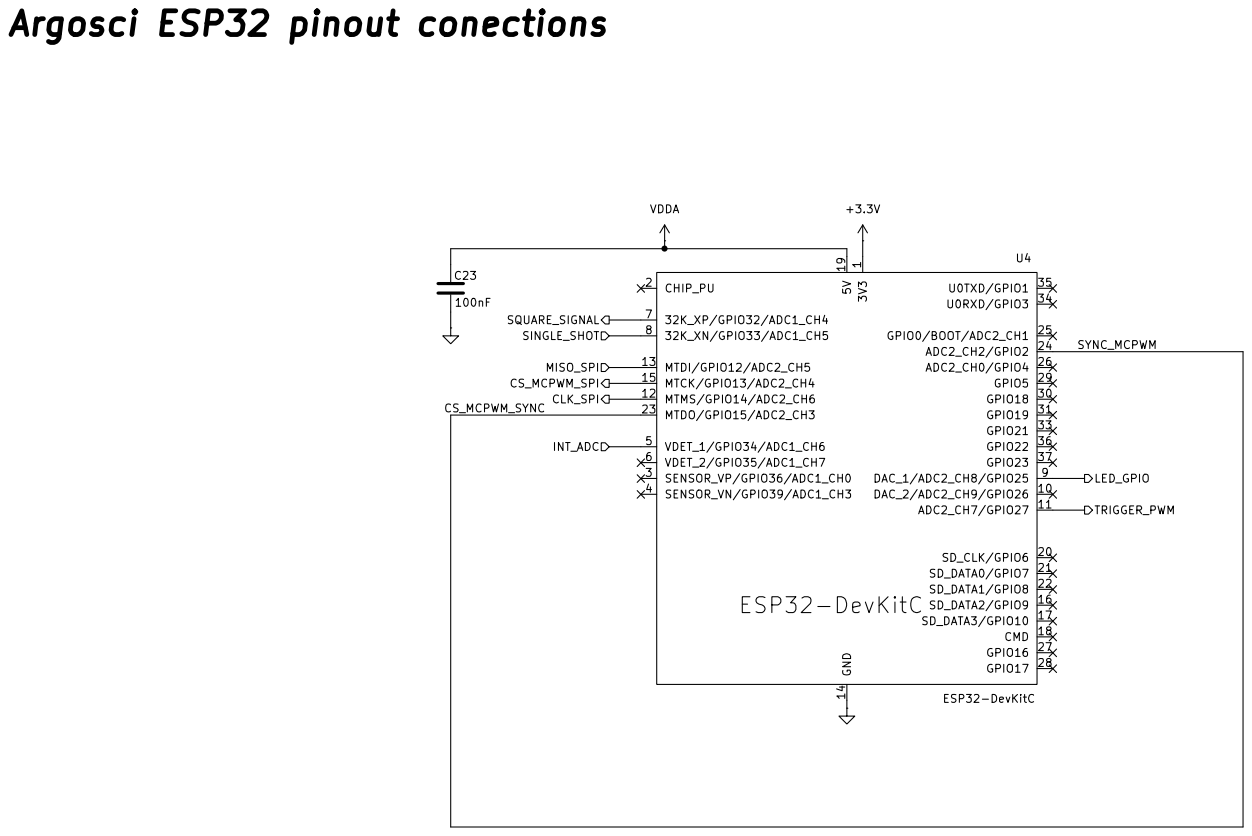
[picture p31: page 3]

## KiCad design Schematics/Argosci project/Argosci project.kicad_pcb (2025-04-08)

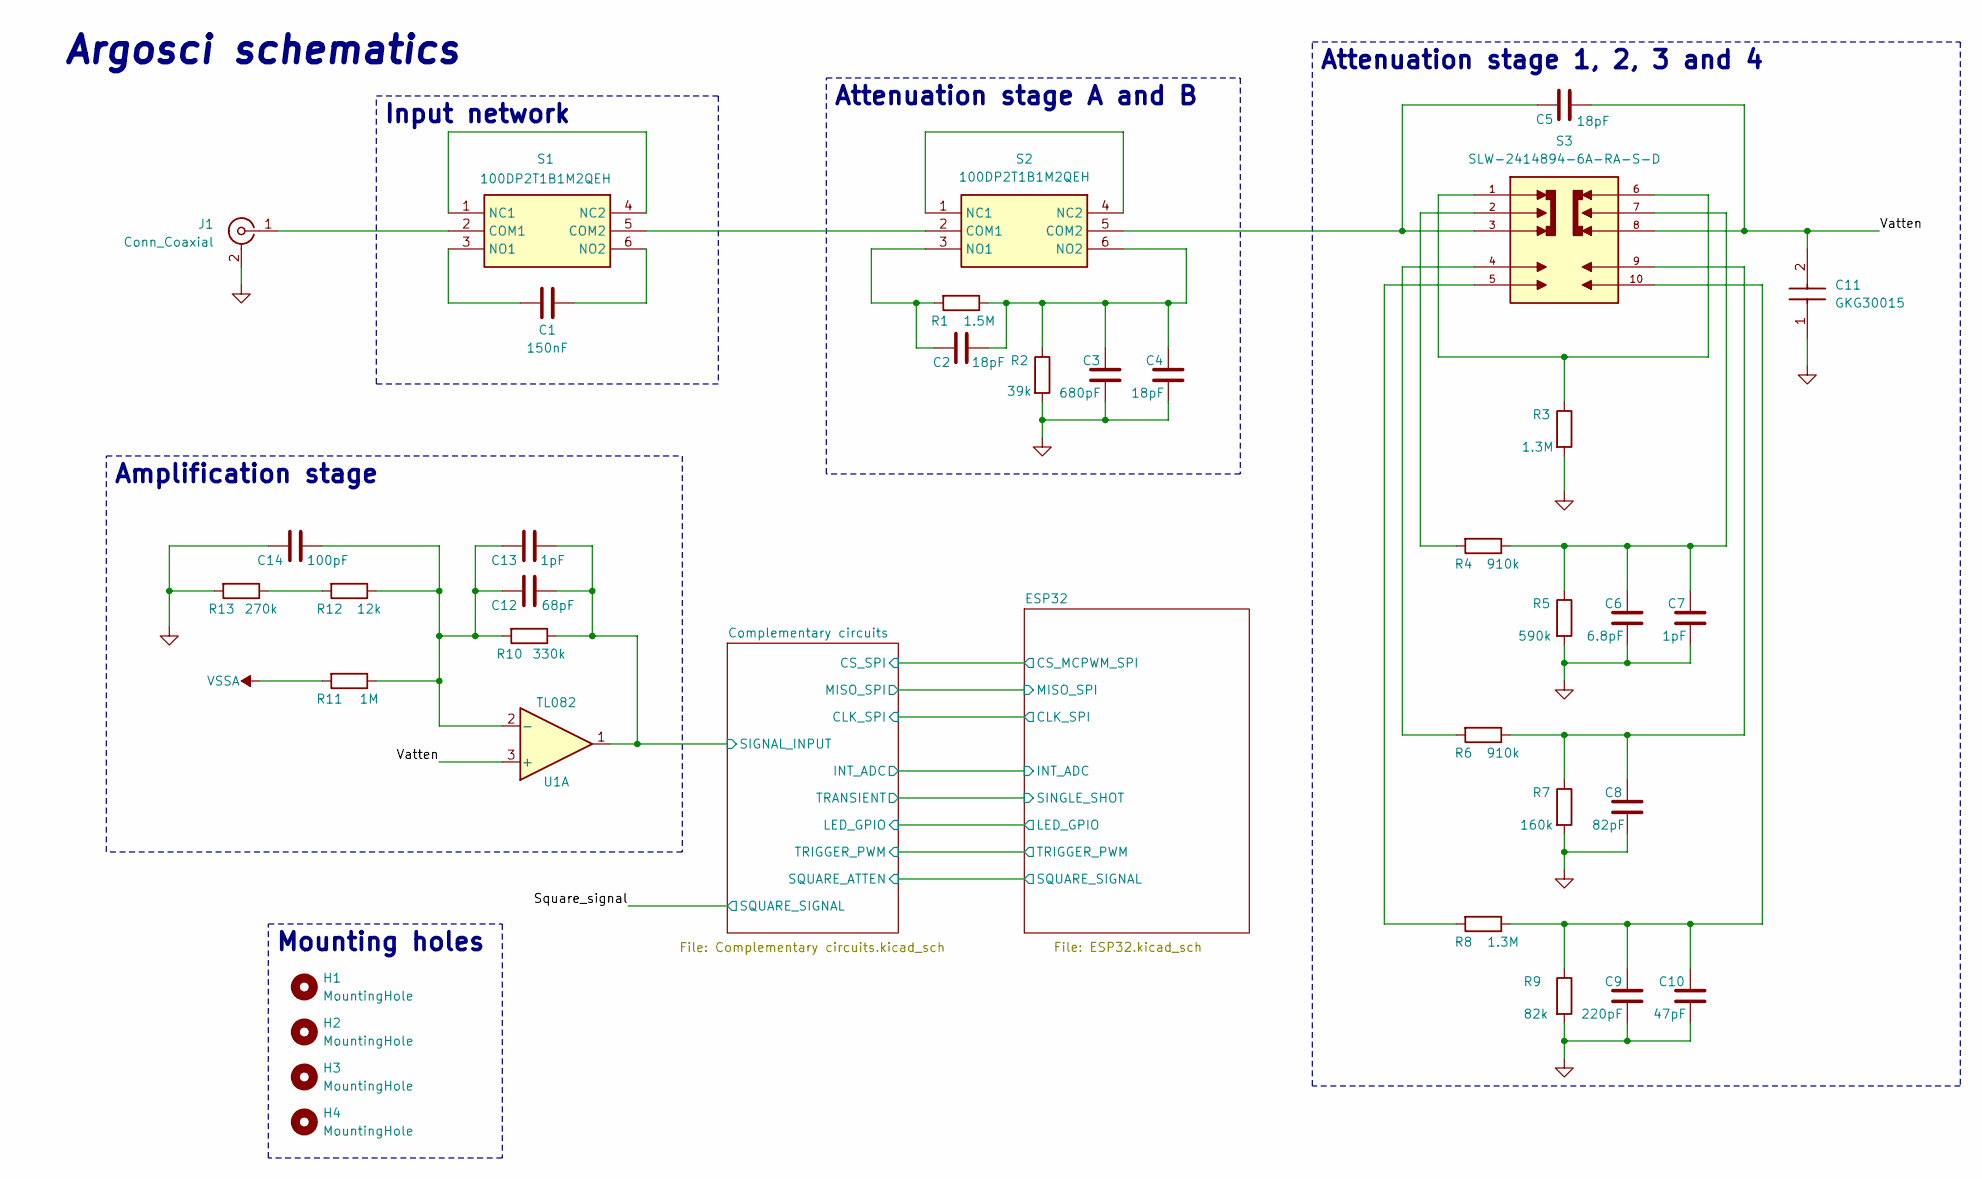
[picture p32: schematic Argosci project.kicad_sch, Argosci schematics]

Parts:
C1: 150nF; C_1206_3216Metric
C2, C4, C5: 18pF; C_1206_3216Metric
C3: 680pF; C_1206_3216Metric
C6: 6.8pF; C_1206_3216Metric
C7, C13: 1pF; C_1206_3216Metric
C8: 82pF; C_1206_3216Metric
C9: 220pF; C_1206_3216Metric
C10: 47pF; C_1206_3216Metric
C11: GKG30015; Mouser Part Number 659-GKG30015
C12: 68pF; C_1206_3216Metric
C14: 100pF; C_1206_3216Metric
H1, H2, H3, H4: MountingHole; MountingHole_3mm
J1: Conn_Coaxial; BNC_Amphenol_B6252HB-NPP3G-50_Horizontal
R1: 1.5M; R_1206_3216Metric
R2: 39k; R_1206_3216Metric
R3, R8: 1.3M; R_1206_3216Metric
R4, R6: 910k; R_1206_3216Metric
R5: 590k; R_1206_3216Metric
R7: 160k; R_1206_3216Metric
R9: 82k; R_1206_3216Metric
R10: 330k; R_1206_3216Metric
R11: 1M; R_1206_3216Metric
R12: 12k; R_1206_3216Metric
R13: 270k; R_1206_3216Metric
S1, S2: 100DP2T1B1M2QEH; Mouser Part Number 612-100DP2T1B1M2QEH
S3: SLW-2414894-6A-RA-S-D; SW_SLW-2414894-6A-RA-S-D; PARTREV 1.01
U1: TL082; DIP-8_W7.62mm

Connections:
/Complementary circuits/SIGNAL_INPUT: C12.2, C13.2, R10.1, U1.1; also elsewhere on the board
/Vatten: C5.2, C11.2, S3.8, U1.3 (+)
GND: C3.2, C4.2, C6.2, C7.2, C8.2, C9.2, C10.2, C11.1, C14.1, J1.2 (Ext), R2.2, R3.2, R5.2, R7.2, R9.2, R13.2; also elsewhere on the board
unnamed: C6.1, C7.1, R4.1, R5.1, S3.7
unnamed: C8.1, R6.1, R7.1, S3.9
unnamed: C9.1, C10.1, R8.1, R9.1, S3.10
unnamed: J1.1 (In), S1.2 (COM1)
unnamed: R3.1, S3.1, S3.6
unnamed: R4.2, S3.2
unnamed: R6.2, S3.4
unnamed: R8.2, S3.5
unnamed: R12.2, R13.1
unnamed: S1.5 (COM2), S2.2 (COM1)
unnamed: S1.1 (NC1), S1.4 (NC2)
unnamed: C1.1, S1.3 (NO1)
unnamed: C1.2, S1.6 (NO2)
unnamed: C5.1, S2.5 (COM2), S3.3
unnamed: S2.1 (NC1), S2.4 (NC2)
unnamed: C2.1, R1.2, S2.3 (NO1)
unnamed: C2.2, C3.1, C4.1, R1.1, R2.1, S2.6 (NO2)
unnamed: C12.1, C13.1, C14.2, R10.2, R11.1, R12.1, U1.2 (-)
VSSA: R11.2; also elsewhere on the board

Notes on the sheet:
Argosci schematics
Input network
Mounting holes
Amplification stage
Attenuation stage 1, 2, 3 and 4
Attenuation stage A and B

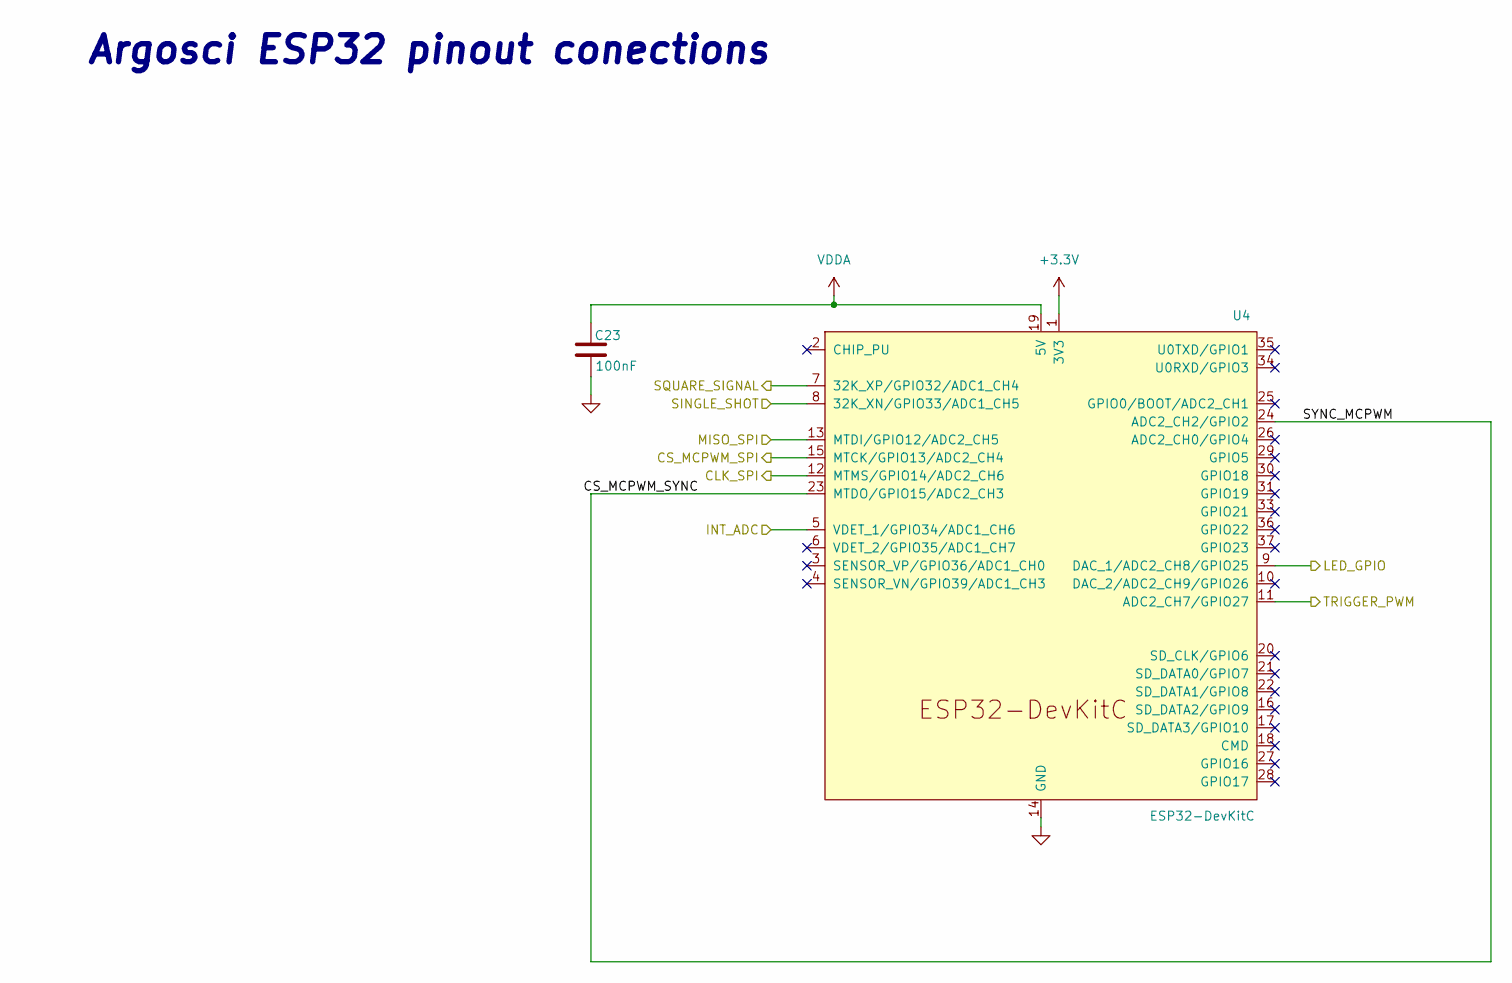
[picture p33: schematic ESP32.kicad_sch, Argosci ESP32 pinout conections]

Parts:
C23: 100nF; C_1206_3216Metric
U4: ESP32-DevKitC

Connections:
+3.3V: U4.1 (3V3); also elsewhere on the board
/Complementary circuits/CLK_SPI: U4.12 (MTMS/GPIO14/ADC2_CH6); also elsewhere on the board
/Complementary circuits/CS_SPI: U4.15 (MTCK/GPIO13/ADC2_CH4); also elsewhere on the board
/Complementary circuits/INT_ADC: U4.5 (VDET_1/GPIO34/ADC1_CH6); also elsewhere on the board
/Complementary circuits/LED_GPIO: U4.9 (DAC_1/ADC2_CH8/GPIO25); also elsewhere on the board
/Complementary circuits/MISO_SPI: U4.13 (MTDI/GPIO12/ADC2_CH5); also elsewhere on the board
/Complementary circuits/SQUARE_ATTEN: U4.7 (32K_XP/GPIO32/ADC1_CH4); also elsewhere on the board
/Complementary circuits/TRANSIENT: U4.8 (32K_XN/GPIO33/ADC1_CH5); also elsewhere on the board
/Complementary circuits/TRIGGER_PWM: U4.11 (ADC2_CH7/GPIO27); also elsewhere on the board
/ESP32/CS_MCPWM_SYNC: U4.23 (MTDO/GPIO15/ADC2_CH3), U4.24 (ADC2_CH2/GPIO2)
GND: C23.2, U4.14 (GND), U4.32 (GND), U4.38 (GND); also elsewhere on the board
VDDA: C23.1, U4.19 (5V); also elsewhere on the board

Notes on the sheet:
Argosci ESP32 pinout conections

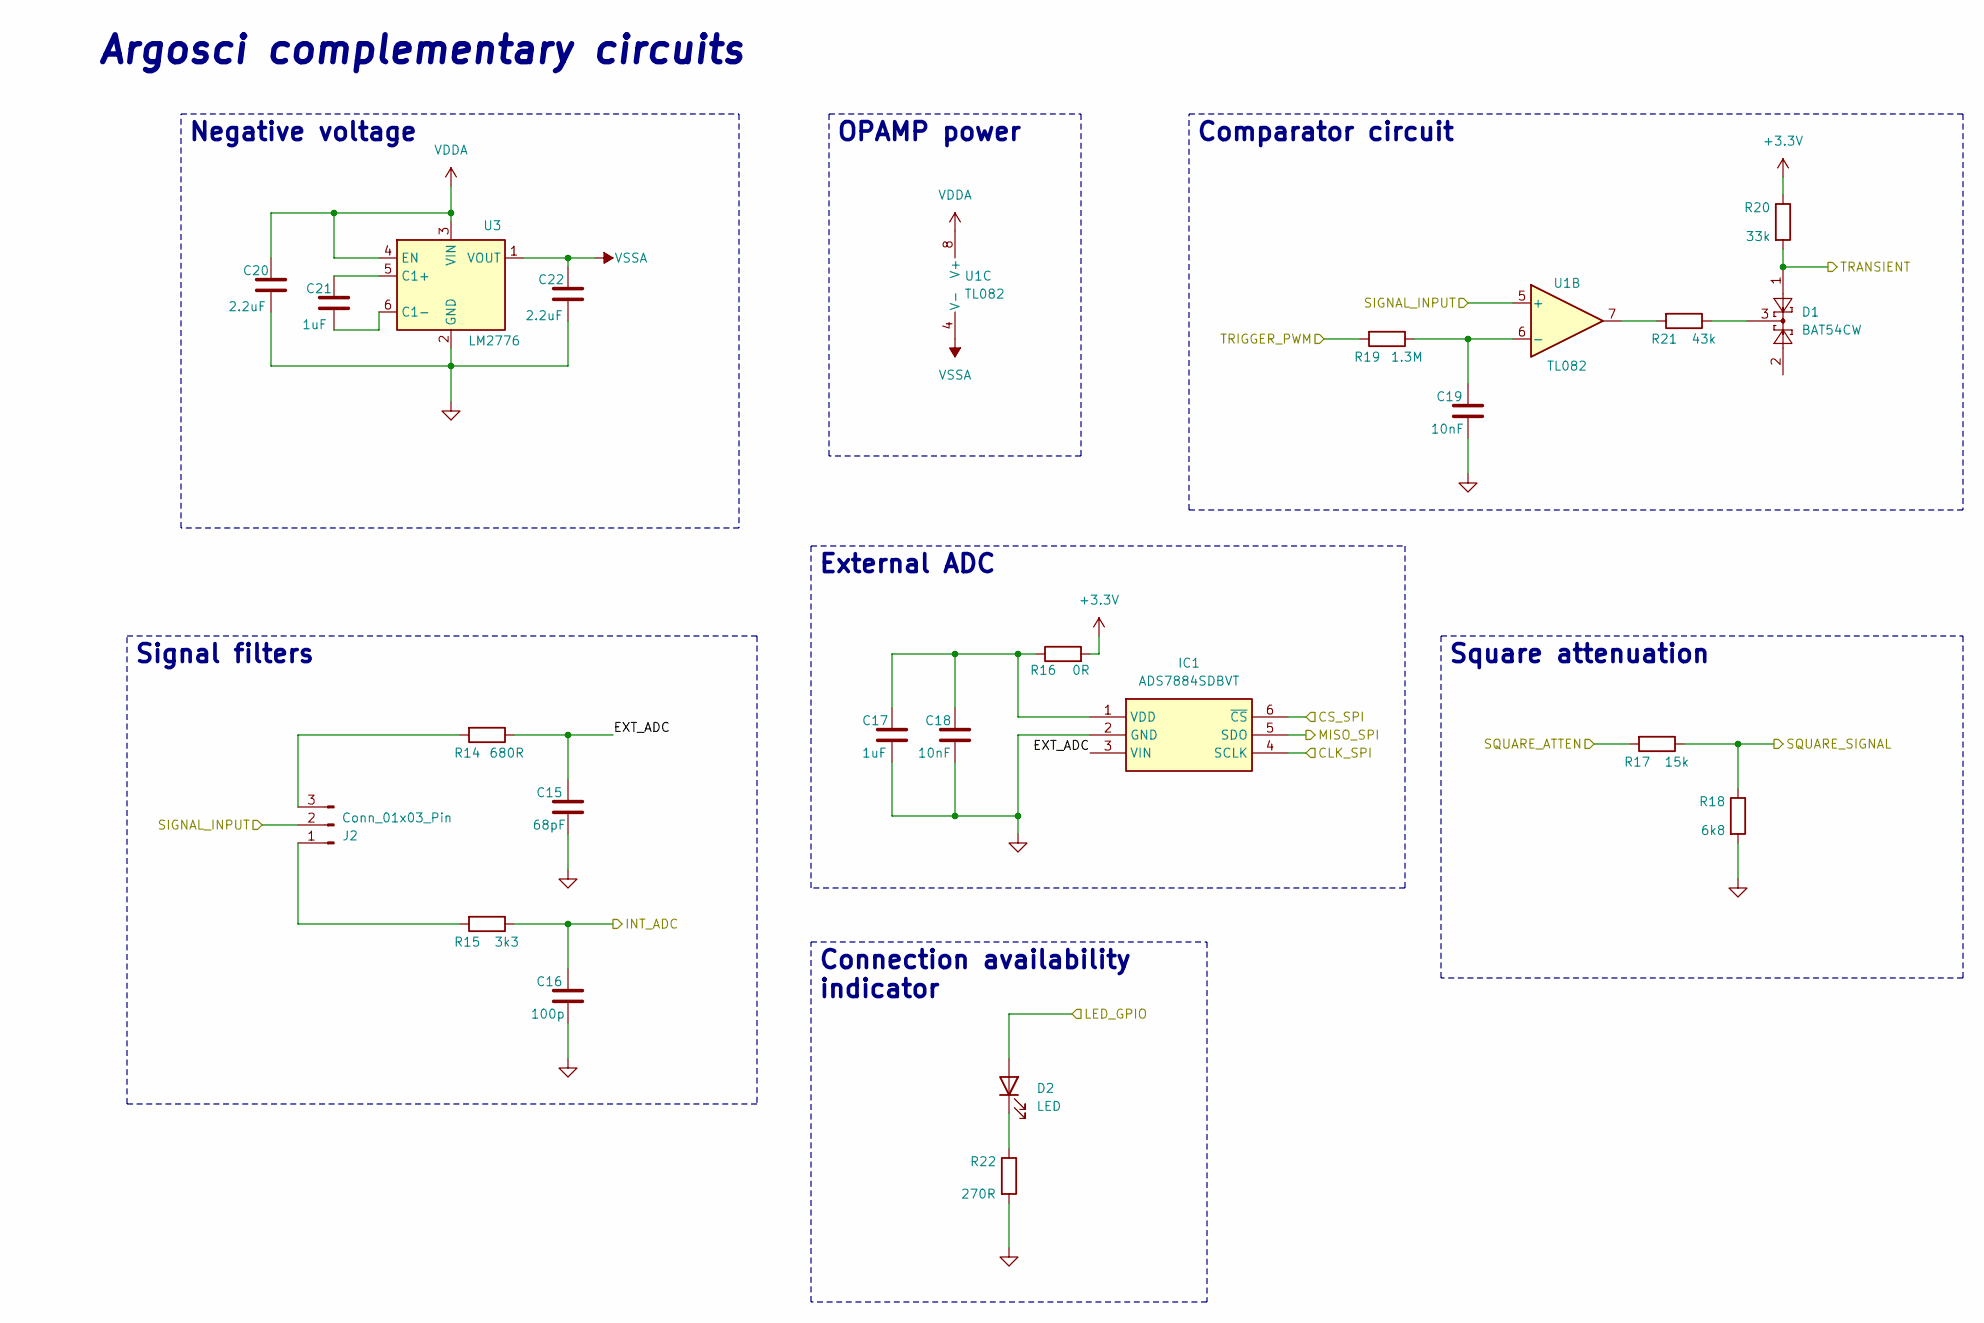
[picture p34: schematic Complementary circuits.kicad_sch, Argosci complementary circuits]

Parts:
C15: 68pF; C_1206_3216Metric
C16: 100p; C_1206_3216Metric
C17, C21: 1uF; C_1206_3216Metric
C18, C19: 10nF; C_1206_3216Metric
C20, C22: 2.2uF; C_1206_3216Metric
D1: BAT54CW; SOT-323_SC-70
D2: LED; LED_D5.0mm
IC1: ADS7884SDBVT; SOT95P280X145-6N; Mouser Part Number 595-ADS7884SDBVT
J2: Conn_01x03_Pin; PinHeader_1x03_P2.54mm_Vertical
R14: 680R; R_1206_3216Metric
R15: 3k3; R_1206_3216Metric
R16: 0R; R_1206_3216Metric
R17: 15k; R_1206_3216Metric
R18: 6k8; R_1206_3216Metric
R19: 1.3M; R_1206_3216Metric
R20: 33k; R_1206_3216Metric
R21: 43k; R_1206_3216Metric
R22: 270R; R_1206_3216Metric
U1: TL082; DIP-8_W7.62mm
U3: LM2776; SOT-23-6

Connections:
+3.3V: R16.2, R20.1; also elsewhere on the board
/Complementary circuits/CLK_SPI: IC1.4 (SCLK); also elsewhere on the board
/Complementary circuits/CS_SPI: IC1.6 (~CS); also elsewhere on the board
/Complementary circuits/EXT_ADC: C15.1, IC1.3 (VIN), R14.1
/Complementary circuits/INT_ADC: C16.1, R15.1; also elsewhere on the board
/Complementary circuits/LED_GPIO: D2.2 (A); also elsewhere on the board
/Complementary circuits/MISO_SPI: IC1.5 (SDO); also elsewhere on the board
/Complementary circuits/SIGNAL_INPUT: J2.2, U1.5 (+); also elsewhere on the board
/Complementary circuits/SQUARE_ATTEN: R17.2; also elsewhere on the board
/Complementary circuits/TRANSIENT: D1.1, R20.2; also elsewhere on the board
/Complementary circuits/TRIGGER_PWM: R19.2; also elsewhere on the board
/Square_signal: R17.1, R18.1
GND: C15.2, C16.2, C17.2, C18.2, C19.2, C20.2, C22.2, IC1.2 (GND), R18.2, R22.2, U3.2 (GND); also elsewhere on the board
unnamed: D1.3, R21.1
unnamed: D2.1 (K), R22.1
unnamed: C17.1, C18.1, IC1.1 (VDD), R16.1
unnamed: J2.1, R15.2
unnamed: J2.3, R14.2
unnamed: R21.2, U1.7
unnamed: C19.1, R19.1, U1.6 (-)
unnamed: C21.1, U3.5 (C1+)
unnamed: C21.2, U3.6 (C1-)
VDDA: C20.1, U1.8 (V+), U3.3 (VIN), U3.4 (EN); also elsewhere on the board
VSSA: C22.1, U1.4 (V-), U3.1 (VOUT); also elsewhere on the board

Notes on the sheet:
Argosci complementary circuits
Signal filters
Connection availability indicator
Square attenuation
External ADC
Negative voltage
OPAMP power
Comparator circuit

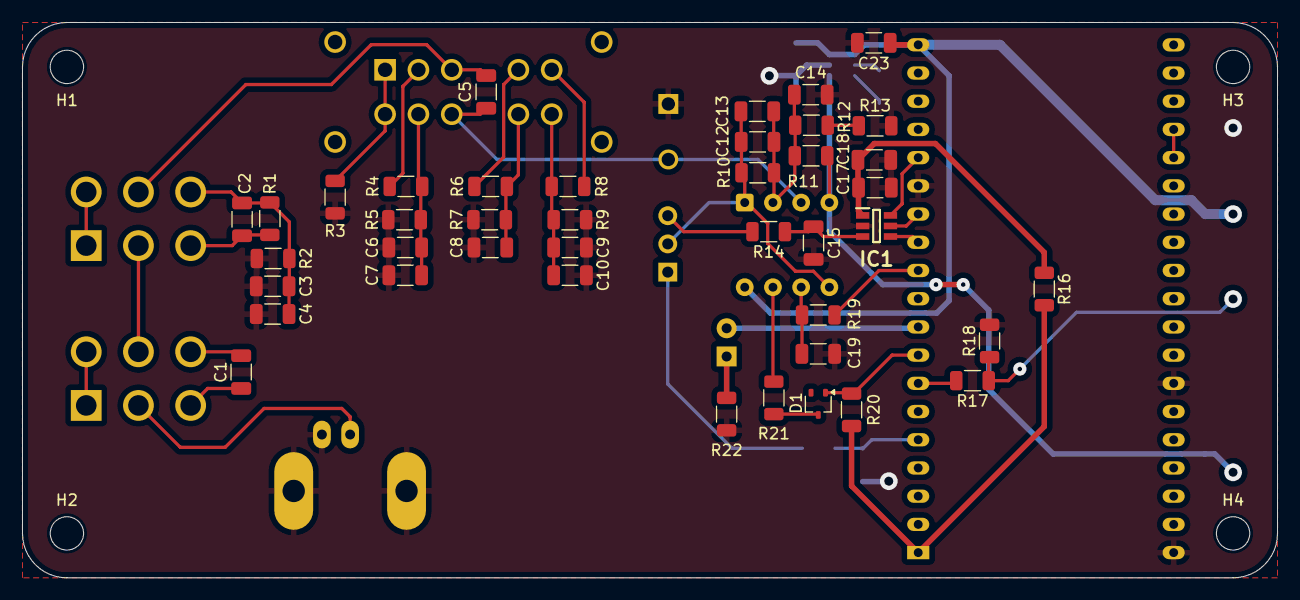
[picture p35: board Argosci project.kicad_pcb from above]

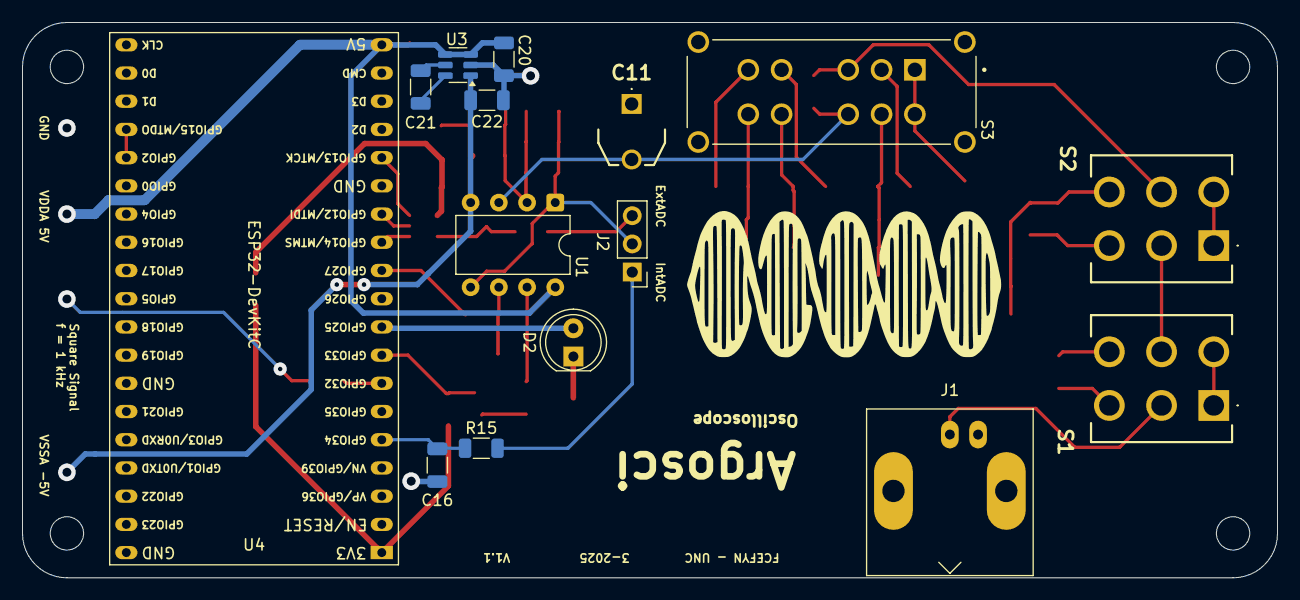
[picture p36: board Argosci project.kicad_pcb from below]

Board: 2 copper layers, 113.0 x 50.0 mm, 60 parts (15 on the bottom side), 44 nets.

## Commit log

2025-04-14 Rename Argosci Through-hole prototype.jpg to ArgosciThrough-holeprototype.jpg
2025-04-14 Rename Bot Side - Argosci PCB.png to BotSide-ArgosciPCB.png
2025-04-14 Rename Bot Side - PCB layout.png to BotSide-PCBlayout.png
2025-04-14 Rename Front-Right Isometric - Argosci PCB and case.png to Front-RightIsometric-ArgosciPCBandcase.png
2025-04-14 Rename Front-Right Isometric - Argosci PCB.png.png to Front-RightIsometric-ArgosciPCB.png
2025-04-14 Rename Front-Right Isometric - Argosci divided case.png to Front-RightIsometric-Argoscidividedcase.png
2025-04-14 Rename Rear-Left Isometric - Argosci PCB and case.png to Rear-Left_Isometric-Argosci_PCB_and_case.png
2025-04-14 Rename Top Side - Argosci PCB and case.png to Top_Side-Argosci_PCB_and_case.png
2025-04-14 Rename Top Side - Argosci PCB.png to Top_Side-Argosci_PCB.png
2025-04-14 Rename Top Side - PCB layout.png to Top_Side-PCB_layout.png
2025-04-28 3D case improvements
    [Argosci 1.1 bot.stl, Argosci 1.1 top.stl]

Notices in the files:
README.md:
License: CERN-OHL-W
